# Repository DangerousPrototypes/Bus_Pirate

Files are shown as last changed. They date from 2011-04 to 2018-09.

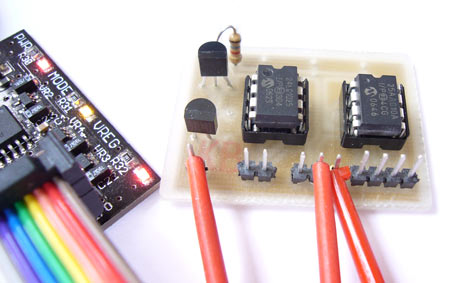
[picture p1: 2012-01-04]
hardware-other/3EEPROM/3EEPROM.v1.jpg

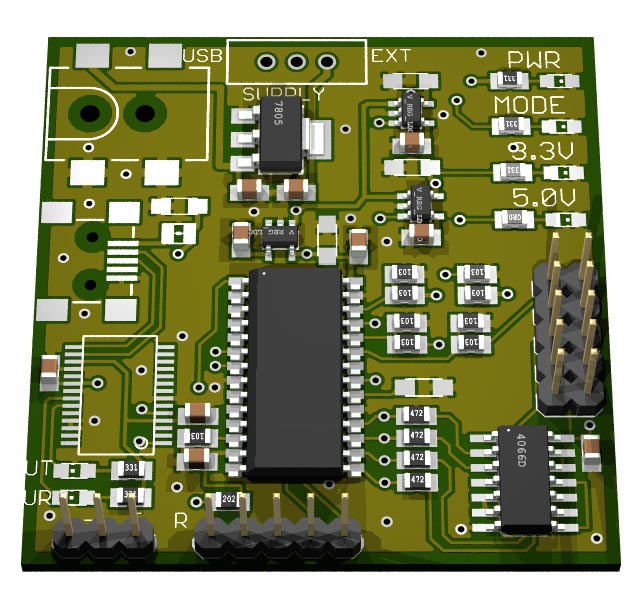
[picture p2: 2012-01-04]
hardware/v2a/BusPirate-v2a-front.jpg

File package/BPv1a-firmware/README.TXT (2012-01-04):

------------------------------------------------------------------
STOP! If you are upgrading from v2 you must install the v4 bootloader first:
http://dangerousprototypes.com/2010/01/18/how-to-bus-pirate-bootloader-v4-upgrade/
v4 BOOTLOADER ONLY!!!
DO NOT TRY TO LOAD THE BOOTLOADER FROM THIS ARCHIVE!!!! 
DO NOT TRY TO LOAD THE V4 FIRMWARE WITH p24QP!!!
------------------------------------------------------------------
Firmware upgrades:

http://dangerousprototypes.com/docs/Bus_Pirate#Firmware_upgrades

1) Enter the bootloader:

Connect PGC and PGD pins of the ICSP header and plug in the USB cable

--+OR+--

Type $ in the Bus Pirate terminal.

With both methods the MODE LED should light.

2) Load the new firmware:

* ds30Loader: just use the GUI (.net/Mono required)
* Pirate-loader (console app for Windows, Linux, Mac) firmware upgrades:

C:\pl>pirate-loader --dev=COM10 --hex=BPv3-Firmware-v1.0.hex

3) re-plug the USB cable to reset the Bus Pirate. The upgrade is complete.

------------------------------------------------------------------
BPv3-Bootloader-v4.4.hex is the same as v4.3 installed with the updater. This file is only for programming the bootlaoder to a new PIC. Use the upgrade package to upgrade:

http://dangerousprototypes.com/docs/Bus_Pirate#Bootloader_upgrades

------------------------------------------------------------------
vX-Firmware-vY(.z_Z).hex

Normal Bus Pirate firmware.
vX - Bus Pirate hardware version.
vY - The Bus Pirate firmware version.
z_Z - The .z_Z versions are translated compiles (currently Spanish and Italian).

vX-STK500v2-vY(-hiz).hex

ATMEL AVR programmer clone for the Bus Pirate hardware. An STK500 v2 protocol compatible firmware for the Bus Pirate, works with AVRDude, AVR Studio v4.11+, etc.
vX - Bus Pirate hardware version (v2go and v3 use the same firmware).
vY - THe STK500v2 clone firmware version.
hiz - The -hiz version of the fimware uses open drain/high impedance outputs. On-board pull-up resistors are enabled (where applicable). The non -hiz version uses normal 3.3volt outputs.

vX-PIC Bootloader-vY.hex

Bootloader to program in a new PIC microcontroller. This is usually only programmed once.
vX - Bus Pirate hardware version.
vY - The Bus Pirate bootloader version.

BPvX-Firmware-vX.X-extras.hex

The BPv3-Firmware-vX.X-extras.hex has a few modes and new stuff we couldn't fit in the main firmware.

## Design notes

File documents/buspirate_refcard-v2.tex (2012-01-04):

\documentclass[10pt]{article}
\usepackage{color}
\begin{document}

%%%%%%%%%%%%%%%%%%%%%%%%%%%%%%%%%%%%%%%%%%%%%%%%%%%%%%%%%%%%%%%%%%%%%%%%%%%%%%%%%%%%%%%%%
%% define colours here 
%% colours are given in normed RGB values
%% whereas (0,0,0) indicates all minimum (black) and (1,1,1) all maximum (white)
%% e.g., \definecolor{MISO}{rgb}{0,0,0}
%% alternatively use 0-255 values by defining the colours with a capital [RGB] parameter
%% e.g., \definecolor{CLK}{RGB}{255,127,0}
%% do not change the given colour names since they correspond to the individual pin
%% These colors are correct at least for my cable dated 10/14/10 ProductNo THM199C4M
%%%%%%%%%%%%%%%%%%%%%%%%%%%%%%%%%%%%%%%%%%%%%%%%%%%%%%%%%%%%%%%%%%%%%%%%%%%%%%%%%%%%%%%%%

\definecolor{GND}{rgb}{0.5,0.1,0.1}  % Brown
\definecolor{V33}{rgb}{1,0,0}        % Red
\definecolor{V5}{rgb}{1,0.5,0}       % Orange
\definecolor{ADC}{rgb}{0.8,0.8,0}    % Yellow (without hurting your eye)
\definecolor{Vpu}{rgb}{0,0.8,0}      % Green
\definecolor{AUX}{rgb}{0,0,1}        % Blue
\definecolor{CLK}{rgb}{0.8,0.4,0.8}  % Purple
\definecolor{MOSI}{rgb}{0.6,0.6,0.6} % Grey
\definecolor{CS}{rgb}{0.9,0.9,0.9}   % White (not really)
\definecolor{MISO}{rgb}{0,0,0}       % Black

%%%%%%%%%%%%%%%%%%%%%%%%%%%%%%%%%%%%%%%%%%%%%%%%%%%%%%%%%%%%%%%%%%%%%%%%%%%%%%%%%%%%%%%%%%%%%%%%%%
% Don't go behind this line without any knowledge of LaTeX and PGF/Tikz... you have been warned
%%%%%%%%%%%%%%%%%%%%%%%%%%%%%%%%%%%%%%%%%%%%%%%%%%%%%%%%%%%%%%%%%%%%%%%%%%%%%%%%%%%%%%%%%%%%%%%%%%

\newcommand{\coltext}[1]{{\textbf{\color{#1}#1}}}

\renewcommand{\arraystretch}{.9}
\setlength{\tabcolsep}{2pt}

\thispagestyle{empty} % just a picture
\sffamily{}\scriptsize
\begin{tabular}{|l|l|l|l|l|l|}
  \hline
    \textbf{SPI}  & \textbf{HiZ} & \textbf{1-Wire} & \textbf{UART} & \textbf{I2C} & \textbf{JTAG}\\ \hline
    \coltext{MISO} & &     & RX &     & TDO \\ \hline
    \coltext{CLK}  & &     &    & SCL & TCK \\ \hline
    \coltext{MOSI} & & OWD & TX & SDA & TDI \\ \hline
    \coltext{CS}   & &     &    &     & TMS \\ \hline
  \hline
    \coltext{AUX} & \multicolumn{5}{|l|}{Auxiliary I/O, freq. probe, PWM} \\ \hline
    \coltext{Vpu} & \multicolumn{5}{|l|}{Input pull-up resistors (0-5V)} \\ \hline
    \coltext{ADC} & \multicolumn{5}{|l|}{A/D\,converter,max.\,6V,10bit,500ksps}\\ \hline
    \textbf{{\color{V5}5V},{\color{V33}3V3}} & \multicolumn{5}{|l|}{Switchable supply, max.\,150mA}\\ \hline
    \coltext{GND} & \multicolumn{5}{|l|}{Ground to test circuit}\\ \hline
  \hline
    \multicolumn{6}{|c|}{\textbf{\tiny BusPirate V3 reference card \hfill dangerousprototypes.com}}\\ 
  \hline
\end{tabular}
\end{document}

%%% Local Variables: 
%%% mode: latex
%%% TeX-master: t
%%% End:

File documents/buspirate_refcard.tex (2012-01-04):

\documentclass[10pt]{article}
\usepackage{pgf}     % drawing in the LaTeX way of life
\usepackage{tikz}    % tikz is not a drawing program
\usepackage[graphics,tightpage,active]{preview} % cut the page to the picture boarders
\setlength{\PreviewBorder}{1pt}  % add a small boarder
\PreviewEnvironment{tikzpicture} 
\begin{document}

%%%%%%%%%%%%%%%%%%%%%%%%%%%%%%%%%%%%%%%%%%%%%%%%%%%%%%%%%%%%%%%%%%%%%%%%%%%%%%%%%%%%%%%%%
%% define colours here 
%% colours are given in normed RGB values
%% whereas (0,0,0) indicates all minimum (black) and (1,1,1) all maximum (white)
%% e.g., \definecolor{MISO}{rgb}{0,0,0}
%% alternatively use 0-255 values by defining the colours with a capital [RGB] parameter
%% e.g., \definecolor{CLK}{RGB}{255,127,0}
%% do not change the given colour names since they correspond to the individual pin
%%%%%%%%%%%%%%%%%%%%%%%%%%%%%%%%%%%%%%%%%%%%%%%%%%%%%%%%%%%%%%%%%%%%%%%%%%%%%%%%%%%%%%%%%

\definecolor{MISO}{rgb}{0,0,0}      % Black
\definecolor{CLK}{rgb}{1,0.5,0}     % Orange
\definecolor{MOSI}{rgb}{1,0,0}      % Red
\definecolor{CS}{rgb}{0.5,0.1,0.1}  % Brown
\definecolor{AUX}{rgb}{0.8,0.8,0}   % Yellow (without hurting your eye)
\definecolor{Vpu}{rgb}{0,0.8,0}     % Green
\definecolor{ADC}{rgb}{0,0,1}       % Blue
\definecolor{V5}{rgb}{0.8,0.4,0.8}  % Violet
\definecolor{V33}{rgb}{0.6,0.6,0.6} % Grey
\definecolor{GND}{rgb}{0.9,0.9,0.9} % White (not really)

%%%%%%%%%%%%%%%%%%%%%%%%%%%%%%%%%%%%%%%%%%%%%%%%%%%%%%%%%%%%%%%%%%%%%%%%%%%%%%%%%%%%%%%%%%%%%%%%%%
% Don't go behind this line without any knowledge of LaTeX and PGF/Tikz... you have been warned
%%%%%%%%%%%%%%%%%%%%%%%%%%%%%%%%%%%%%%%%%%%%%%%%%%%%%%%%%%%%%%%%%%%%%%%%%%%%%%%%%%%%%%%%%%%%%%%%%%

\thispagestyle{empty} % just a picture
  \begin{tikzpicture}[scale=1, node distance=0,inner sep=0.3] % no scaling, no distance between nodes, set inner separation between text and nodes
    \sffamily{}\scriptsize
    \tikzstyle{mynode} = [draw=none,fill=none,anchor=center] % define a own style for all this text-nodes
    
    \matrix[row sep=0.1cm,column sep=0.075cm,anchor=north west] at (0,2.85) % create the first matrix similar to a Latex table 
    {
                                             & \node[mynode] {\textbf{HiZ}}; & \node[mynode] {\textbf{1-Wire}}; & \node[mynode] {\textbf{UART}}; & \node[mynode] {\textbf{I2C}}; & \node[mynode] {\textbf{SPI}}; & \node[mynode] {\textbf{JTAG}};\\
      \node[mynode,right,color=MISO] {\textbf{MISO}};   &                               & \node[mynode]{OWD};              & \node[mynode]{TX};             & \node[mynode]{SDA};           & \node[mynode]{MOSI};          & \node[mynode]{TDI};\\
      \node[mynode,right,color=CLK] {\textbf{CLK}};  &                               &                                                                   & \node[mynode] {SCL};          & \node[mynode]{CLK};         & \node[mynode]{TCK};\\
      \node[mynode,right,color=MOSI] {\textbf{MOSI}};   &                               &                                  & \node[mynode] {RX};            &                               & \node[mynode]{MISO};          & \node[mynode]{TDO};\\
      \node[mynode,right,color=CS] {\textbf{CS}};    &                               &                                  &                                &                               & \node[mynode]{CS};            & \node[mynode]{TMS};\\
    };
    \matrix[row sep=0cm,column sep=0cm,right,anchor=south west] at (0,0.2) % create the second matrix 
    {
    \node[mynode,right,color=AUX]{\textbf{AUX}};      & \node[mynode,right] {Auxiliary I/O, freq. probe, PWM}; \\
    \node[mynode,right,color=Vpu]{\textbf{Vpu}};      & \node[mynode,right] {Input pull-up resistors (0-5V)}; \\
    \node[mynode,right,color=ADC]{\textbf{ADC}};      & \node[mynode,right] {A/D\,converter,max.\,6V,10bit,500ksps}; \\
    \node[mynode,right]{\textbf{{\color{V5}5V},{\color{V33}3.3V}}};  & \node[mynode,right] {Switchable supply, max.\,150mA}; \\
    \node[mynode,right,color=GND]{\textbf{GND}};      & \node[mynode,right] {Ground to test circuit}; \\
    };
    \foreach \y in {0,1,2,3,4}  % draw the grid
        \draw[gray] (0,2.65-0.3*\y)--++(5,0);
    \foreach \x in {0.75,1.275,2.125,2.95,3.55,4.3} 
        \draw[gray] (\x,2.9)--++(0,-1.45);
    \draw[gray] (0,0) rectangle ++(5,2.9); % draw a rectangle with the size of the pcb
    \node[right] at (0,0.1) {\tiny bus-pirate reference card, dangerousprototypes.com, \hspace{0.4cm}V1.0}; % add some infos
  \end{tikzpicture}
\end{document}

%%% Local Variables: 
%%% mode: latex
%%% TeX-master: t
%%% End:

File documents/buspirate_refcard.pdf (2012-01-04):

HiZ | 1-Wire | UART | I2C | SPI | JTAG
MISO | OWD | TX | SDA | MOSI | TDI
CLK | | SCL | CLK | TCK
MOSI | | RX | | MISO | TDO
CS | | | | CS | TMS
AUX | Auxiliary I/O, freq. probe, PWM
Vpu | Input pull-up resistors (0-5V)
ADC | A/D converter,max. 6V,10bit,500ksps
5V,3.3VSwitchable supply, max. 150mA
GND | Ground to test circuit
bus-pirate reference card, dangerousprototypes.com, | V1.0

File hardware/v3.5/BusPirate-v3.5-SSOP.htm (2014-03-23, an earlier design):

Part | Quantity | Value | Package
C1-C6 | 6 | 0.1uF | C603
C7,C8,C9 | 3 | 1uF | C603
C10,C11 | 2 | 10uF | SMC_A
H1,H2,H3,H4 | 4 | MOUNT-PAD-ROUND3.0 | 3,0-PAD
I/O | 1 | HEADER2X5-SHRD-PTH | PINSHRD_PTH_2X05
IC1 | 1 | PIC24FJ64GA002 | SSOP28
IC2 | 1 | FT232RL | SSOP28
IC3 | 1 | 4066 | TSSOP14
ICSP | 1 | HEADER_PRG_PIC_ICSP | HEADER_PRG_1X05_ICSP_B
J1 | 1 | CONN_USB | CONN_USB_MINI-B@1
L1 | 1 | 700mA+ ferrite | WE-KI_0805_B
LED1-LED2,LED2A-LED2,LED3A-LED2,LED4A,LED4A | 8 | | CHIP-LED0805
R1,R5 | 2 | 2K | R603
R2,R3,R4,R6 | 4 | 1K1 | R603
RN1,RN2,RN3 | 3 | 10k | RN8P-4R-CRA06S
U$1 | 1 | | DP-LOGO
U$2 | 1 | | DP-LOGO-BOTTOM
VR1,VR2 | 2 | MCP1801T-3302I/OT | SOT-23-5
VR3 | 1 | MCP1801T-5002I/OT | SOT-23-5

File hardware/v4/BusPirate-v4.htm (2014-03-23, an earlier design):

Part | Quantity | Value | Package
C1-C6,C9,C9 | 8 | 0.1uF | C0603
C7,C8 | 2 | 27pF | C0603
C11,C13 | 2 | 1uF | C0603
C12 | 1 | 1uf | C0603
C14,C15 | 2 | 10uF | SMC_A
D1,D2,D3 | 3 | | SOD123
H1,H2,H3,H4 | 4 | MOUNT-PAD-ROUND2.8 | 2,8-PAD
IC1 | 1 | PIC24FJ256GB106 | TQFP64-10X10
IC2 | 1 | 4066D | SO14
IC3 | 1 | 24AASOT-23-5 | SOT-23-5
ICSP | 1 | ICSP | 1X05
IO | 1 | PINSHRD-PTH-2X06 | PINSHRD_PTH_2X06
JP1 | 1 | | 1X02-S
L1 | 1 | 700mA+ ferrite bead | WE-KI_0805_B
LED1-LED2,LED2A-LED2,LED3A-LED2,LED4A,LED4A | 8 | | CHIP-LED0805
NORMAL,RESET | 2 | SMD_TACT_SMALL | TACT_SWITCH_SMALL
Q1,Q2 | 2 | | SOT23
R1,R2 | 2 | 1K | R0603
R3,R4,R5,R6 | 4 | 1K1 | R0603
R7,R8,R9,R10 | 4 | 2K | R0603
R11,R12,R13,R14 | 4 | 10K | R0603
R15 | 1 | 100K | R0603
RN1,RN2,RN3 | 3 | 10k | RN8P-4R-CRA06S
U$1 | 1 | | DP-LOGO
USB | 1 | USB mini-b | CONN_USB_MINI-B
VR1,VR2 | 2 | MCP1801T-3302I/OT | SOT-23-5
VR3 | 1 | MCP1801T-5002I/OT | SOT-23-5
X1 | 1 | CRYSTAL_212M_ | 4X6

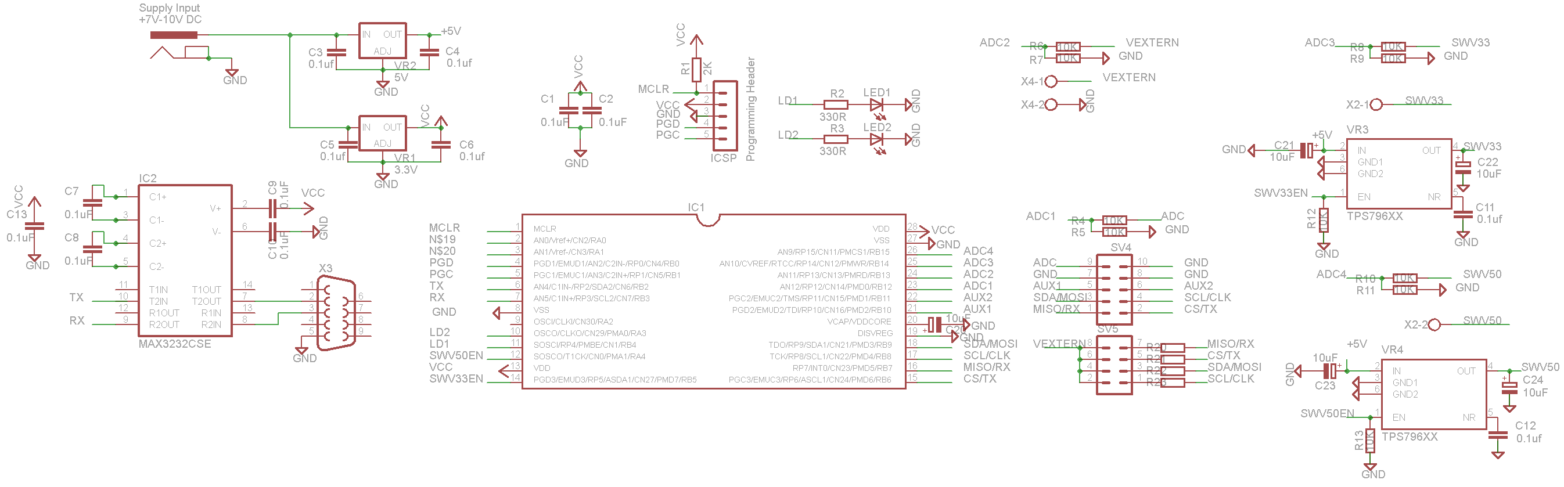
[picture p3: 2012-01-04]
hardware/v1a/cct.png

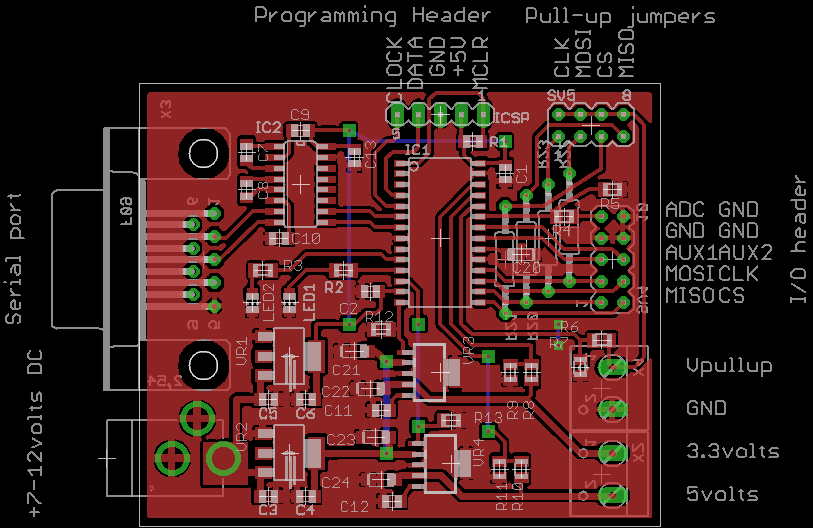
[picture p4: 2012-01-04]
hardware/v1a/brd.png

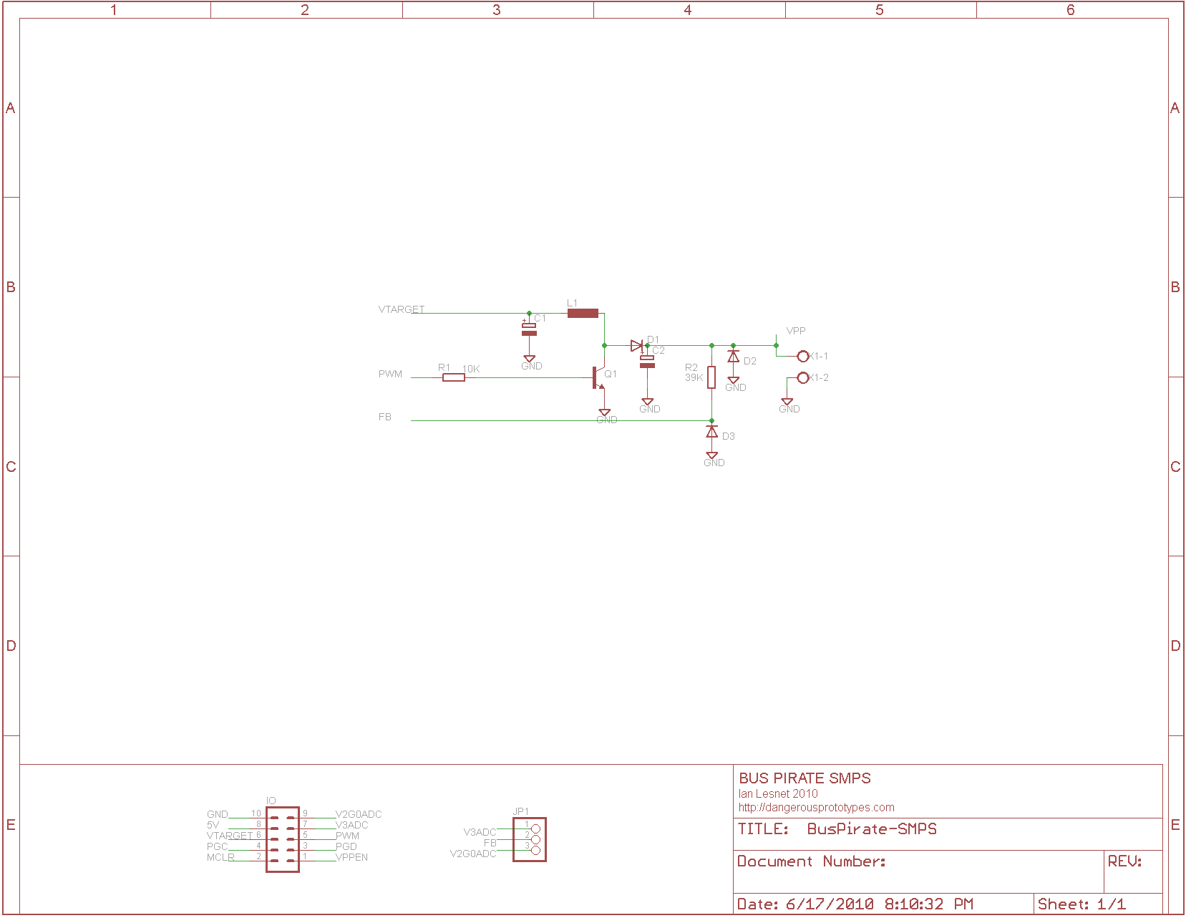
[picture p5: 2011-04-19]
hardware-other/SMPS/BusPirate-SMPS.sch.png

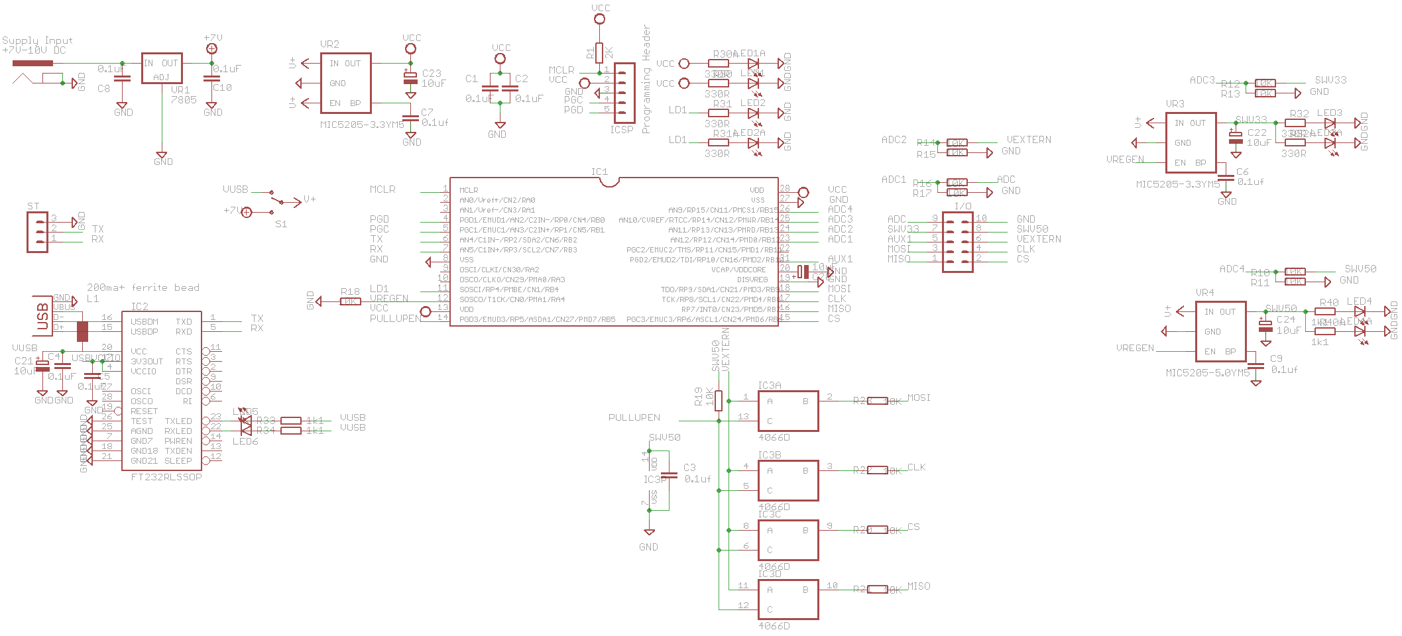
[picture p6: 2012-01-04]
hardware/v2a/cct.png

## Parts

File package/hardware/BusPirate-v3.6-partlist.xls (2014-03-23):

Electronic Engineering BOM List v1.0
Product Name： Bus Pirate
Version： Version v3.6
Issue Date： 05/01/12
Item No. (序号) | Catalog (分类） | Reference Des (上件位置) | Part_Description (规格描述) | Part_Value （元件值） | Part_Package （元件封装） | Qty (用量) | Manufacturers Name (使用厂牌名称) | Manufacturers Part No. (使用厂牌型号) | Distributors Name （供应商名称） | Distributors Part No. (供貨商型号) | Unit Price （单价） | Price Break To Use （价格分段的购买量） | Stock Status （库存状态） | Notes/Remark （备注）
1 | Capacitor | C1,C2,C3,C4,C5,C6 | Ceramic Capacitor | 0.1uF | C603 | 6
2 | Capacitor | C7, C8,C9 | Ceramic Capacitor | 1uF | C603 | 3
3 | Capacitor | C10,C11 | Tantalum capacitor | 10uF | SMC_A | 2
4 | OTHER | I/O | 05x2 shrouded header. Note: Shrouded | M05X2SHD | 2X5-SHROUDED | 1
5 | IC | IC1 | PIC microcontroller | PIC24FJ64GA002SS | SSOP28DB | 1
6 | IC | IC2 | FT232RLSSOP |  | SSOP28DB | 1
7 | IC | IC3 | 74HC4066 or CD4066 |  | TSSOP14 | 1
8 | OTHER | ICSP | 0.1” male pin header | M05X1PTH | 1X05 | 1
9 | OTHER | J1 | CONN_USB |  | CONN_USB_MINI-B | 1
10 | OTHER | L1 | 700mA+ ferrite bead | 700mA+ | L805 | 1
11 | OTHER | LED1 – 4 | Yellow LEDs |  | LED0805 | 4
12 | Resister | R1,R5 |  | 2K | R603 | 2
13 | Resister | R2,R3,R4,R6 |  | 1K1 | R603 | 4
14 | OTHER | RN1,RN2,RN3 | 4 resistor array | 10k | R0603 x 4 array | 3
15 | OTHER | VR1,VR2 | 3.3volt LDO voltage regulator 150mA with enable (example MCP1801T-3302I/OT) | MCP1801T-3302I/OT | SOT23-5 | 2 | http://ph.mouser.com/ProductDetail/Microchip-Technology/MCP1801T-3302I-OT/
16 | OTHER | VR3 | 5volt LDO voltage regulator 150mA with enable (example MCP1801T-5002I/OT) | MCP1801T-5002I/OT | SOT23-5 | 1 | http://ph.mouser.com/ProductDetail/Microchip-Technology/MCP1801T-5002I-OT/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
1. Recommended Distributors: Digi-Key, Mouser, Avnet Express, Farnell.
2. Catalog: Capacitor,Resister,Diode,Connector,Transistor,IC,PROTECTOR CATEGORY,OTHER
3. Required Fields: Item No, Reference Des, Qty, Catalog, Part_Value, Part_Package, Part_Description
Optional Fields: Manufacturers Name, Manufacturers Part No, Distributors Name, Distributors Part No, Unit Cost, Price break to use, Stock Status，Notes/Remark
 |  |  |  |  |  |  |  |  | by Heidi Luo
 |  |  |  |  |  |  |  |  | 01.May/2011

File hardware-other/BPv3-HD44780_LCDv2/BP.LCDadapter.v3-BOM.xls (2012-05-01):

Electronic Engineering BOM List v1.0
Product Name： Bus Pirate LCD adapter
Version： Version 3
Issue Date： 5/01/12
Item No. (序号) | Catalog (分类） | Reference Des (上件位置) | Part_Description (规格描述) | Part_Value （元件值） | Part_Package （元件封装） | Qty (用量) | Manufacturers Name (使用厂牌名称) | Manufacturers Part No. (使用厂牌型号) | Distributors Name （供应商名称） | Distributors Part No. (供貨商型号) | Unit Price （单价） | Price Break To Use （价格分段的购买量） | Stock Status （库存状态） | Notes/Remark （备注）
1 | OTHER | ANODE,CATH,CPWM | 0.1” pin header |  | 1X02 | 1
2 | OTHER | ANODE,CATH,CPWM | 0.1” pin header |  | 1X03 | 1
3 | Capacitor | C1 |  | 0.1uF | C0805 | 1
4 | IC | IC1 | 74HCT595D (NOTE: Please make it "HCT") |  | SO16 | 1
5 | OTHER | JP1 | M05X2SHD |  | 2X5-SHROUDED | 1
6 | OTHER | LCD | 0.1” Female header |  | 1X16 | 1
7 | OTHER | LED1 | Yellow LED |  | CHIP-LED0805 | 1
8 | Resister | R1 |  | 10K trim resistor 6mm | CA6V | 1
9 | Resister | R2,R4 |  | 1K | M0805 | 2
10 | Resister | R5 |  | 100R trim resistor 6mm | CA6V | 1
11 | Transistor | T1 | NPN 800ma+ (BC818) |  | SOT23-BEC | 1
12 | OTHER | Jumpers | 0.1” jumper on ANODE,CATH |  |  | 2
13 | OTHER | Cable | 2x5 to 2x5 ribbon cable |  |  | 1
1. Recommended Distributors: Digi-Key, Mouser, Avnet Express, Farnell.
2. Catalog: Capacitor,Resister,Diode,Connector,Transistor,IC,PROTECTOR CATEGORY,OTHER
3. Required Fields: Item No, Reference Des, Qty, Catalog, Part_Value, Part_Package, Part_Description
Optional Fields: Manufacturers Name, Manufacturers Part No, Distributors Name, Distributors Part No, Unit Cost, Price break to use, Stock Status，Notes/Remark
 |  |  |  |  |  |  |  |  | by Heidi Luo
 |  |  |  |  |  |  |  |  | 01.5/2012

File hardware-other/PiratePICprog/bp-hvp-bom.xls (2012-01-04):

Part | Quantity | Value
C1 | 1 | 470pF capacitor (0805) (http://www.mouser.com/ProductDetail/Xicon/140-CC501N471J-RC/)
C2, C3, C6 | 3 | 0.1uF/50V capacitor (0805) (http://www.mouser.com/Search/ProductDetail.aspx)
C4 | 1 | 10uF/10V capacitor (SMC_A) (http://www.mouser.com/Search/ProductDetail.aspx)
C5 | 1 | 4.7uF/35V (SMD_A5) (http://www.mouser.com/Search/ProductDetail.aspx)
D1, D2 | 2 | 1N5819, 20V, 1A+ diode (SOD123) (http://www.mouser.com/Search/ProductDetail.aspx)
IC1 | 1 | MC34063AD (SO08) (http://www.mouser.com/Search/ProductDetail.aspx)
JP1 | 1 | female 02x5 plug (http://www.mouser.com/Search/ProductDetail.aspx)
L1 | 1 | 680uH/0.12A inductor (L4532P) (http://www.mouser.com/Search/ProductDetail.aspx?R=84684Cvirtualkey58010000virtualkey580-84684C)
PIC-ICSP | 1 | 1X05 0.1” pin header (http://www.mouser.com/Search/ProductDetail.aspx)
POWER | 1 | 1X03 0.1” pin header (http://www.mouser.com/Search/ProductDetail.aspx)
R1 | 1 | 20K resistor (0805) (http://www.mouser.com/Search/ProductDetail.aspx)
R2 | 1 | 2K2 resistor (0805) (http://www.mouser.com/Search/ProductDetail.aspx)
R3 | 1 | 4R7 resistor (0805) (http://www.mouser.com/ProductDetail/Xicon/260-47-RC/)
R4 | 1 | 180R resistor (0805) (http://www.mouser.com/Search/ProductDetail.aspx)
R5 | 1 | 39K resistor (0805) (http://www.mouser.com/Search/ProductDetail.aspx?R=260-39K-RCvirtualkey21980000virtualkey260-39K-RC)
R6 | 1 | 100K resistor (0805) (http://www.mouser.com/Search/ProductDetail.aspx)
R7 | 1 | 100R resistor (0805) (http://www.mouser.com/Search/ProductDetail.aspx)
R8-R12 | 5 | 10K resistor (0805) (http://www.mouser.com/Search/ProductDetail.aspx)
T1, T2 | 2 | NPN, 200mA+, 30+hfe transistor (SOT23-BEC) (http://www.mouser.com/Search/ProductDetail.aspx)
T3,T4 | 2 | PNP, 600mA+, 40+ hef transistor (SOT23-BEC) (http://www.mouser.com/Search/ProductDetail.aspx)
Jumper | 1 | 1 jumper on the power header

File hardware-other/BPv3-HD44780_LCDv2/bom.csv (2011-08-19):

Part | Value | Package
BLA | 1x2 0.1” pin header | 1X02
BLC | 1x2 0.1” pin header | 1X02
C1 | 0.1uF capacitor | 805
IC1 | 74HCT595 | SO16
JP1 | 5X2 0.1” shrouded header | 2X5-SHROUDED
LCD1 | 14x1 0.1” female header | 14x1 (female)
LED1 | Yellow LED | 805
R1 | 10K potentiometer | CA6V/6mm
R2 | 1K resistor | 805
CABLE | 6cm 1x10 cable with 2 2x5 female connectors
 | This cable connects the Bus Pirate to the LCD adapter
 | It needs 2x5 female connectors on each end.
 | Length can be very short >6cm.

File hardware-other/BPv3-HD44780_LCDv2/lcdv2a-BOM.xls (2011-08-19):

Partlist
Bus Pirate LCD Adapter v2a
Where Labs, LLC
Contact: Ian Lesnet (ian@wherelabs.com)
Part | Value | Package
ANODE | 1x2 0.1” pin header | 1X02
CATH | 1x2 0.1” pin header | 1X02
C1 | 0.1uF capacitor | 805
IC1 | 74HCT595 | SO16 | **note orientation
JP1 | 5X2 0.1” shrouded header | 2X5-SHROUDED | **note orientation
LCD1 | 16x1 0.1” female header | 16x1 (female)
LED1 | Yellow LED | 805 | **note orientation
R1 | 10K potentiometer | CA6V/6mm
R2 | 1K resistor | 805
CABLE | 6cm 1x10 cable with 2 2x5 female connectors
 | This cable connects the Bus Pirate to the LCD adapter
 | It needs 2x5 female connectors on each end.
 | Length can be very short >6cm.

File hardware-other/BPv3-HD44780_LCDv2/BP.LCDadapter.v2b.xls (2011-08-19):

Bus Pirate LCD adapter v2b
Ian Lesnet (ian@wherelabs.com)
Part | Quantity | Value | Package
ANODE,CATH,CPWM | 3 | 0.1” pin header | 1X02
C1 | 1 | 0.1uF | C0805
IC1 | 1 | 74HCT595D | SO16
JP1 | 1 | M05X2SHD | 2X5-SHROUDED
LCD | 1 | 0.1” Female header | 1X16
LED1 | 1 | Yellow LED | CHIP-LED0805
R1 | 1 | 10K trim resistor 6mm | CA6V
R2,R4 | 2 | 1K | M0805
R5 | 1 | 100R trim resistor 6mm | CA6V
T1 | 1 | NPN 800ma+ (BC818) | SOT23-BEC
Jumpers | 2 | 0.1” jumper on ANODE,CATH
Cable | 1 | 2x5 to 2x5 ribbon cable

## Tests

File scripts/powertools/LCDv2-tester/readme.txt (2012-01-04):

Latest instructions and version:
http://dangerousprototypes.com/docs/Bus_Pirate_LCD_adapter_v2#Production_testing_procedure

Setup a Bus Pirate for testing
#Use Bus Pirate with firmware v5.x
#Connect the Bus Pirate to USB
#Run lcdtest.exe -d COMx where COMx is the Bus Pirate serial port.

Test procedure
#Connect the LCD adapter the the Bus Pirate
#Press space to run the test
#Verify LED1 on the adapter is blinking (other outputs will also blink)
#Press space to reset the test
#Remove the LCD adapter
#Repeat with #1

Possible no LED solutions
*Check LED1, R2 (solder, failed)
*Check IC1 (solder, failed)
*Check IO connector (solder)

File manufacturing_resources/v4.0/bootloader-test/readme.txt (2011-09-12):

http://dangerousprototypes.com/docs/Bus_Pirate_v4_firmware_updates

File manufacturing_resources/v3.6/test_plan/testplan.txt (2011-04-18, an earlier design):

http://dangerousprototypes.com/docs/Self-test_guide

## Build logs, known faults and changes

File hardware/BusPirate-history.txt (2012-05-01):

May 1, 2012
v4d
*Updated PCB to fit DP6037 standard PCB footprint
*Updated silk with big logos

v3.6
*Renamed v3.5e to avoid confusion with cases

v3.5e
*Updated to fit DP6037 standard PCB footprint
*Updated silk with big logos

****Old history****

v4.1 (lost variant)
*Small rerouting of v4
*not yet resized to fit v4a case
*Lost or abandonded

v4a
*v4 resized to fit Seeed case. First production version.

v4
*Original pre-production version 4 sold at Seeed for $50.

v3.5c
*Replaced 4066 control trace

v3.5b
*Header keyed to match seeed cable

v3.5
*Two versions, SOIC and SSOP PIC chips
*Same as v3b with reduced part count
*Resistors moved to resistor arrays
*Centered connectors and jacks
*SSOP size 4066 (instead of SOIC on v3)

v3b
*Same as v3a 
*Ceremic instead of tantalum capacitors for the 3.3 and 5volt regulators

v3a
*First Dangerous Prototypes version
*Reshaped the original v2go hardware
*Moved to SOIC PIC chip

v2go
*Original Seeed Studio preorder Bus Pirate hardware

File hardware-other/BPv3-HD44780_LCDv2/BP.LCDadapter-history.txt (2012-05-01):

v3
*Silk update with logo
*Board shape change to fit standard PCB footprint for cases
*PART REDUCTION: v2c uses 3pcs 1x2 pin headers. v3 uses 1pc 1x2 and 1pcs 1x3

v2c
*Silk cleanup

v2b
*Added backlight adjustable resistor
*Silk cleanup

v2a
*Added T1 and R4 to do backlight dimming with the Bus Pirate PWM.

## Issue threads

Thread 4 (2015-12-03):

0Tis Elevat0r C0mpany R3mote Stati0n Pr0tocol

nicolas-schurando, 2015-12-03:
I am importing this issue from the old google code repository, https://code.google.com/p/the-bus-pirate/issues/detail?id=37.

alvaro.e...@gmail.com, Sep 5, 2009
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

ianles...@gmail.com, Sep 6, 2009
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

BrentBXR, Nov 22, 2011
>0 1c th4t 15 s0o c0ol. I would imagine people working on elevators have specialized equipment todo so. I would never take my bus pirate to go hacking elevators. Not that the bus pirate shouldn't have every protocol it can fit. It just seems this would be on the rarely, if ever, used list. I doubt Ian or the DP guys could make time to implement it when other, more used, protocols are still pending.
>
>co0l u5ag3 of num8er5 a5 13773r5 7h0, rather annoying really. :P

Although this was discussed many years ago now, it does not appear the questions have been answered, and I believe it could still be of interest for some people. At least, for me it is. So here is some information I have gathered so far.

On modern generations (gen2 for example), the bus is composed of 4 wires. L1 (for data), L2 (for clock), +30VDC and GND. It would make sense for the clock to be generated by the main controller. I would assume it is some kind of I2C.

As the bus runs for dozens of meters down the hoistway, special care should probably be taken when designing an adaptation circuit for the bus pirate since capacitance and pull-up resistor values will have an impact on achievable data rates.

Cheers.

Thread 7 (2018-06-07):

Where could I read more about Bus Pirate v5.0 ?

mikebdp2, 2018-06-07:
@vimark I can't find any mention of " Bus Pirate v5.0 " at DangerousPrototypes website ( no new results at http://dangerousprototypes.com/blog/category/bus-pirate/ ). Where could I read more about Bus Pirate v5.0 ? And is it a completely new hardware, or its actually based on Bus Pirate v3 and should be called Bus Pirate v3.9 or v3.10 not to confuse the people?

vimark, 2018-06-07:
Sorry, We don't have that version yet.

mikebdp2, 2018-06-07:
@vimark Thank you for reply! Please tell, is BPv5 a completely new hardware, or its actually based on Bus Pirate v3 and is fully compatible with it by its' bootloader/firmware ? Just need to clarify...

vimark, 2018-06-08:
@mikebdp2 From hardware point of view its completely new. Sorry, but I can't comment  much on the firmware side as I only do on hardware on it.

kallisti5, 2018-07-02:
The community firmware project has gotten pretty advanced and has a *LOT* of fixes and cleanups of the original BusPirate firmware.  Dangerous Prototypes would be pretty silly not to leverage their advances in any "theoretical" new BusPirate hardware.

mikebdp2, 2018-08-16:
@vimark I fully support @kallisti5 point of view. Please improve your collaboration with the community

mikebdp2, 2018-08-16:
@ian Hope you could check this thread above, and this one also - https://github.com/BusPirate/Bus_Pirate/issues/98

kallisti5, 2018-08-16:
I should also mention that the community firmware would *love* to work with DP if needed.. but someone from DP needs to collaborate.

kallisti5, 2018-08-16:
also, looking at this it doesn't seem DP is interested at the moment in the community firmware and all of it's fixes and improvements:

https://github.com/DangerousPrototypes/Bus_Pirate/tree/firmware_v8_official

DangerousPrototypes, 2018-08-16:
Hey Mike,

We're really working on it. I'm stuck behind the Chinese firewall and its difficult to explain the extent to which the internet doesn't work. This is the first email I've received on this chain, I don't know of there are others. Half the time github access is blocked here.

I'm actually moving back to Amsterdam starting in September and we have a bunch of stuff ready to roll out. For example we managed to get buspirate.com back from the spammers that took over after hack a day and have setup a site there with continuous development integration for all versions of the bus pirate (instantly compiling the latest git commits and packaging them into releases). We plan to make this open source too to help other projects focus more on coding and less on tedious release management.

I've already reworked v3/4/5 code base with about two dozen fixes. I just need to be where the internet works to start posting about it.

V5 is a minor tweak, but v NG1 is a complete remake, and NG2 is probably the ultimate tool we can make for cheap with modern chips.

⁣Cheers,

Ian

Sent from a mobile device, please excuse my brevity.

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

DangerousPrototypes, 2018-08-16:
Sjaak and I have reviewed and have a private branch to merge in eventually. We like many of the changes, but there's a lot of stuff that we want to do differently based on our experience with the compilers and code base.

⁣Cheers,

Ian

Sent from a mobile device, please excuse my brevity.

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

kallisti5, 2018-08-16:
No worries, that's all fine.   We have been stuck with silence from DP for a few years now, so we really don't know what to expect.

The https://github.com/BusPirate/Bus_Pirate source repository is **really** in good shape thanks to @agatti  The code has been cleaned up, updated to the most recent MPLab X, and had a **huge** number of bug fixes (and new features) introduced.

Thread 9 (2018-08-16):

DP Forums - Cant register: reCAPTCHA V1 IS SHUTDOWN

mikebdp2, 2018-08-16:
Dear Administrators, @vimark and @ian, I am writing to you with a really urgent matter. New members can't register at DangerousPrototypes forums, because

Confirmation of Registration:
reCAPTCHA V1 IS SHUTDOWN
Direct site owners to http://g.co/recaptcha/upgrade

You could try registering a new account by yourself, to easily see this problem. Please do something, maybe upgrade this captcha switch to the alternative domestic captcha to avoid depending on the stupid google

http://dangerousprototypes.com/forum/ucp.php?mode=register

Please read this thread - https://github.com/BusPirate/Bus_Pirate/issues/98 - btw it also describes the questions of DP collaboration with the community

DangerousPrototypes, 2018-08-16:
Hey ya,

Im super sorry about the issue and I'm aware of it. Its on our list. Edward is working on it. Its really hard because phpbb is less than an ideal code base to work with. We need a path forward that will maintain current integration with the site. We also need akismet or similar spam filtering because phpbb is a spam magnet. If we upgrade phpbb then we loose our current home grown spam hammer filter. I also refuse to use the Google "choose the store fronts" "choose the street signs" because it is blocked in China and elsewhere, and also its so frustrating to use.

⁣Cheers,

Ian

Sent from a mobile device, please excuse my brevity.

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

DangerousPrototypes, 2018-08-16:
Part of that is everyone uses CDC hosted libraries (jquery, font awesome, bootstrap, Google fonts, etc) like life depends on them. Half these are blocked in China and time out and break web pages even if the page itself isn't blocked. It causes a huge amount of lag outside China too.

If you look at how we did dirtypcbs.com we use raw javascript when possible, and if we include a library we host it locally (out of nessesity). Buspirate.com is made the same way.

I'm in Shenzhen at the moment running test batches of new hardware. I'll be back in Amsterdam on the 4th to start dealing with updates and community side.

Thanks for liking what we do! It means a lot. We are hard at work readying the new stuff for fall. Getting all these emails today gives us lots of encouragement that someone will be interested in our progress.

⁣Cheers,

Ian

Sent from a mobile device, please excuse my brevity.

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

mikebdp2, 2018-09-19:
@DangerousPrototypes Thank you very much to you and your team for fixing the captcha. This issue could be closed now...

theolas, 2023-11-27:
@DangerousPrototypes Hi, sorry to bother, it seems like the site is not secured (expired certificate?) and the email validation emails are not reaching the mailboxes, so new accounts cannot be created.

DangerousPrototypes, 2024-01-29:
Please try our new site forum.buspirate.com. I'm going to rip all the old DP sites to flatfile because the underlying tech is too old to migrate anywhere. Sorry for a very late reply, I think we touched bases on twitter too.

Closed 2018-09-19.

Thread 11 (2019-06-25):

Firmware Updating

kkey00, 2019-06-25:
So I updated the firmware on my bus pirate v3 and it gave me the success message. However when I try to use screen to check the firmware version the interface doesn't function. I can put the board in boot loader mode with a jumper, but not through the console anymore. The power LED is on and so is the VREG LED. Any help is appreciated!

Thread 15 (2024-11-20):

si7021 command not working

grymoire, 2024-11-20:
I can follow the [Device Demo for SL7021](https://firmware.buspirate.com/devices/si7021), and all of the individual commands work, but the command "si7021" returns an error
```
I2C> si7021           
Read temperature and humidity from SI7021/HTU21/SHT21 sensor
Error reading humidity data
```
[BUGSI7021.txt](https://github.com/user-attachments/files/17835094/BUGSI7021.txt)

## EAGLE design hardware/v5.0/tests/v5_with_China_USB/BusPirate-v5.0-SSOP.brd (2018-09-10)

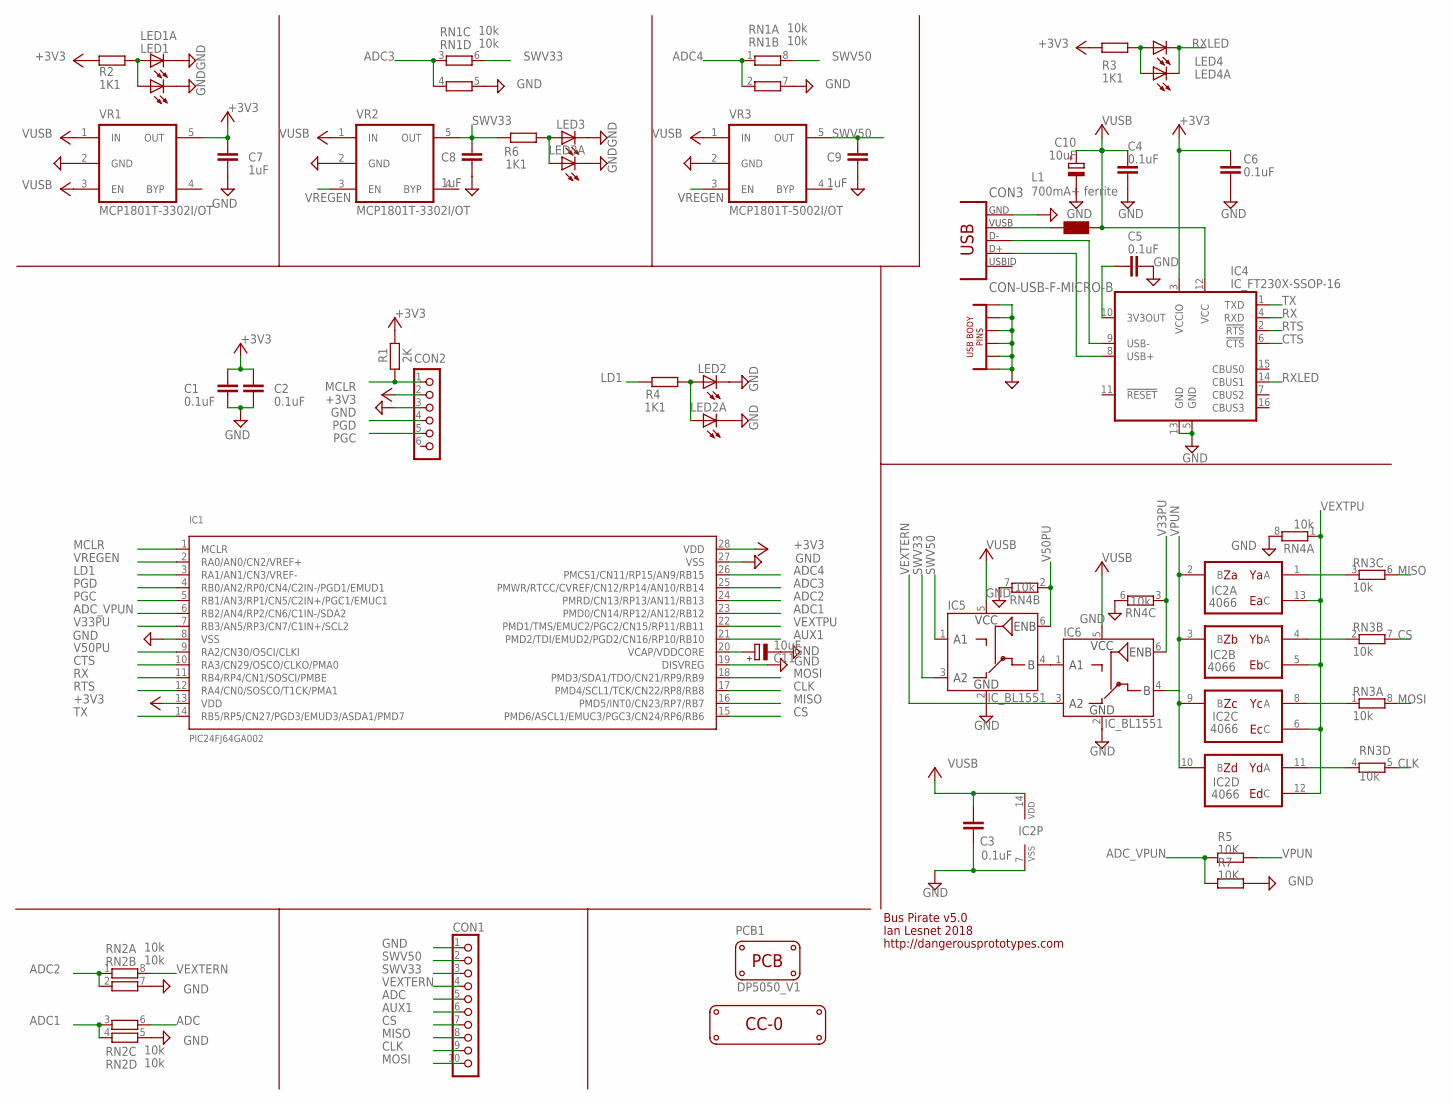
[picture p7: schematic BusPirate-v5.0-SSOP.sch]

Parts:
C1, C2, C3, C4, C5, C6: 0.1uF; C603
C7, C8, C9: 1uF; C603
C10, C11: 10uF; SMC_A
CON1: CON_HEADER_1X10-RIGHT_ANGLED_PTH_SHROUDED; M1X10_MALE_RIGHT_ANGLES_PTH_SHROUDED
CON2: CON_HEADER_1X06-PTH; M1X6
CON3: CON-USB-F-MICRO-B; CON_USB_MICRO-B-1-MD05SMXXX-01
IC1: PIC24FJ64GA002; SSOP28
IC2: 4066; TSSOP14
IC4: IC_FT230X-SSOP-16; SSOP-16-FTDI
IC5, IC6: IC_BL1551; SOT-363
L1: 700mA+ ferrite; WE-KI_0805_B
LED1, LED1A, LED2, LED2A, LED3, LED3A, LED4, LED4A: LED-0805; LED-805
LOGO1: LOGO_CC-0
PCB1: PCB_DP_SQUARE-5X5; DP5050_V1
R1: 2K; R603
R2, R3, R4, R6: 1K1; R603
R5, R7: 10K; R603
RN1, RN2, RN3, RN4: 10k; RN8P-4R-CRA06S
VR1, VR2: MCP1801T-3302I/OT; SOT-23-5
VR3: MCP1801T-5002I/OT; SOT-23-5

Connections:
$N26: CON3.P1 (VUSB), L1.2 (1)
+3V3: C1.1, C2.1, C6.1, C7.1, CON2.2, IC1.13 (VDD), IC1.28 (VDD), IC4.3 (VCCIO), R1.2, R2.2, R3.2, VR1.5 (OUT)
ADC: CON1.5, RN2.6 (2)
ADC1: IC1.23 (PMD0/CN14/RP12/AN12/RB12), RN2.3 (1), RN2.4 (1)
ADC2: IC1.24 (PMRD/CN13/RP13/AN11/RB13), RN2.1, RN2.2 (1)
ADC3: IC1.25 (PMWR/RTCC/CVREF/CN12/RP14/AN10/RB14), RN1.3 (1), RN1.4 (1)
ADC4: IC1.26 (PMCS1/CN11/RP15/AN9/RB15), RN1.1, RN1.2 (1)
ADC_VPUN: IC1.6 (RB2/AN4/RP2/CN6/C1IN-/SDA2), R5.2, R7.2
AUX1: CON1.6, IC1.21 (PMD2/TDI/EMUD2/PGD2/CN16/RP10/RB10)
CLK: CON1.9, IC1.17 (PMD4/SCL1/TCK/CN22/RP8/RB8), RN3.5 (2)
CS: CON1.7, IC1.15 (PMD6/ASCL1/EMUC3/PGC3/CN24/RP6/RB6), RN3.7 (2)
CTS: IC1.10 (RA3/CN29/OSCO/CLKO/PMA0), IC4.6 (!CTS)
GND: C1.2, C2.2, C3.2, C4.2, C5.2, C6.2, C7.2, C8.2, C9.2, C10.-, C11.-, CON1.1, CON2.3, CON3.GND1, CON3.GND2, CON3.GND3, CON3.GND4, CON3.GND5, CON3.GND6, CON3.P5 (GND), IC1.8 (VSS), IC1.19 (DISVREG), IC1.27 (VSS), IC2.7 (VSS), IC4.5 (GND), IC4.13 (GND), IC5.2 (GND), IC6.2 (GND), LED1.C, LED1A.C, LED2.C, LED2A.C, LED3.C, LED3A.C, R7.1, RN1.5 (2), RN1.7 (2), RN2.5 (2), RN2.7 (2), RN4.6 (2), RN4.7 (2), RN4.8 (2), VR1.2 (GND), VR2.2 (GND), VR3.2 (GND)
LD1: IC1.3 (RA1/AN1/CN3/VREF-), R4.2
MCLR: CON2.1, IC1.1 (MCLR), R1.1
MISO: CON1.8, IC1.16 (PMD5/INT0/CN23/RP7/RB7), RN3.6 (2)
MOSI: CON1.10, IC1.18 (PMD3/SDA1/TDO/CN21/RP9/RB9), RN3.8 (2)
unnamed: IC2.11 (A), RN3.4 (1)
unnamed: IC2.8 (A), RN3.1
unnamed: C11.+, IC1.20 (VCAP/VDDCORE)
unnamed: IC2.4 (A), RN3.2 (1)
unnamed: IC2.1 (A), RN3.3 (1)
unnamed: LED2.A, LED2A.A, R4.1
unnamed: LED1.A, LED1A.A, R2.1
unnamed: C5.1, IC4.10 (3V3OUT)
unnamed: IC5.4 (B), IC6.1 (A1)
unnamed: LED4.A, LED4A.A, R3.1
unnamed: CON3.P3 (D+), IC4.8 (USB+)
unnamed: CON3.P2 (D-), IC4.9 (USB-)
unnamed: LED3.A, LED3A.A, R6.1
PGC: CON2.5, IC1.5 (RB1/AN3/RP1/CN5/C2IN+/PGC1/EMUC1)
PGD: CON2.4, IC1.4 (RB0/AN2/RP0/CN4/C2IN-/PGD1/EMUD1)
RTS: IC1.12 (RA4/CN0/SOSCO/T1CK/PMA1), IC4.2 (!RTS)
RX: IC1.11 (RB4/RP4/CN1/SOSCI/PMBE), IC4.4 (RXD)
RXLED: IC4.14 (CBUS1), LED4.C, LED4A.C
SWV33: C8.1, CON1.3, IC5.3 (A2), R6.2, RN1.6 (2), VR2.5 (OUT)
SWV50: C9.1, CON1.2, IC5.1 (A1), RN1.8 (2), VR3.5 (OUT)
TX: IC1.14 (RB5/RP5/CN27/PGD3/EMUD3/ASDA1/PMD7), IC4.1 (TXD)
V33PU: IC1.7 (RB3/AN5/RP3/CN7/C1IN+/SCL2), IC6.6 (ENB), RN4.3 (1)
V50PU: IC1.9 (RA2/CN30/OSCI/CLKI), IC5.6 (ENB), RN4.2 (1)
VEXTERN: CON1.4, IC6.3 (A2), RN2.8 (2)
VEXTPU: IC1.22 (PMD1/TMS/EMUC2/PGC2/CN15/RP11/RB11), IC2.5 (C), IC2.6 (C), IC2.12 (C), IC2.13 (C), RN4.1
VPUN: IC2.2 (B), IC2.3 (B), IC2.9 (B), IC2.10 (B), IC6.4 (B), R5.1
VREGEN: IC1.2 (RA0/AN0/CN2/VREF+), VR2.3 (EN), VR3.3 (EN)
VUSB: C3.1, C4.1, C10.+, IC2.14 (VDD), IC4.12 (VCC), IC5.5 (VCC), IC6.5 (VCC), L1.1 (2), VR1.1 (IN), VR1.3 (EN), VR2.1 (IN), VR3.1 (IN)

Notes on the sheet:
Bus Pirate v5.0
Ian Lesnet 2018
http://dangerousprototypes.com

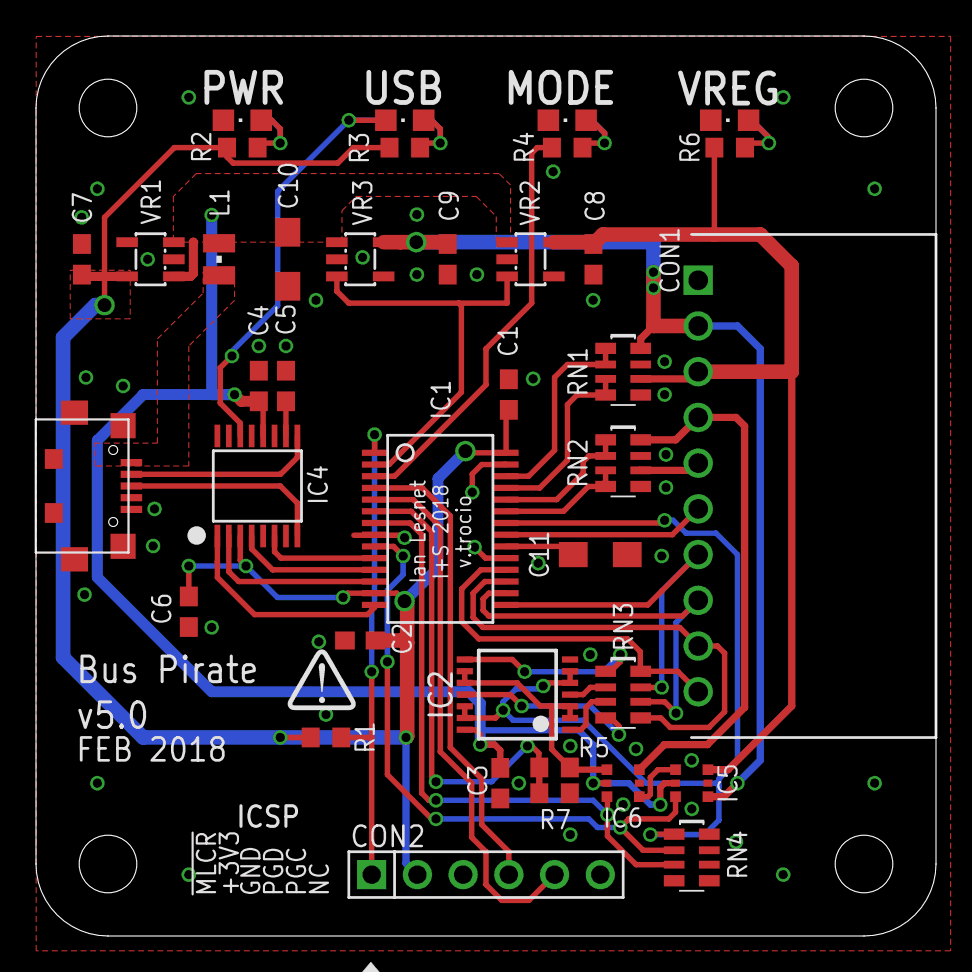
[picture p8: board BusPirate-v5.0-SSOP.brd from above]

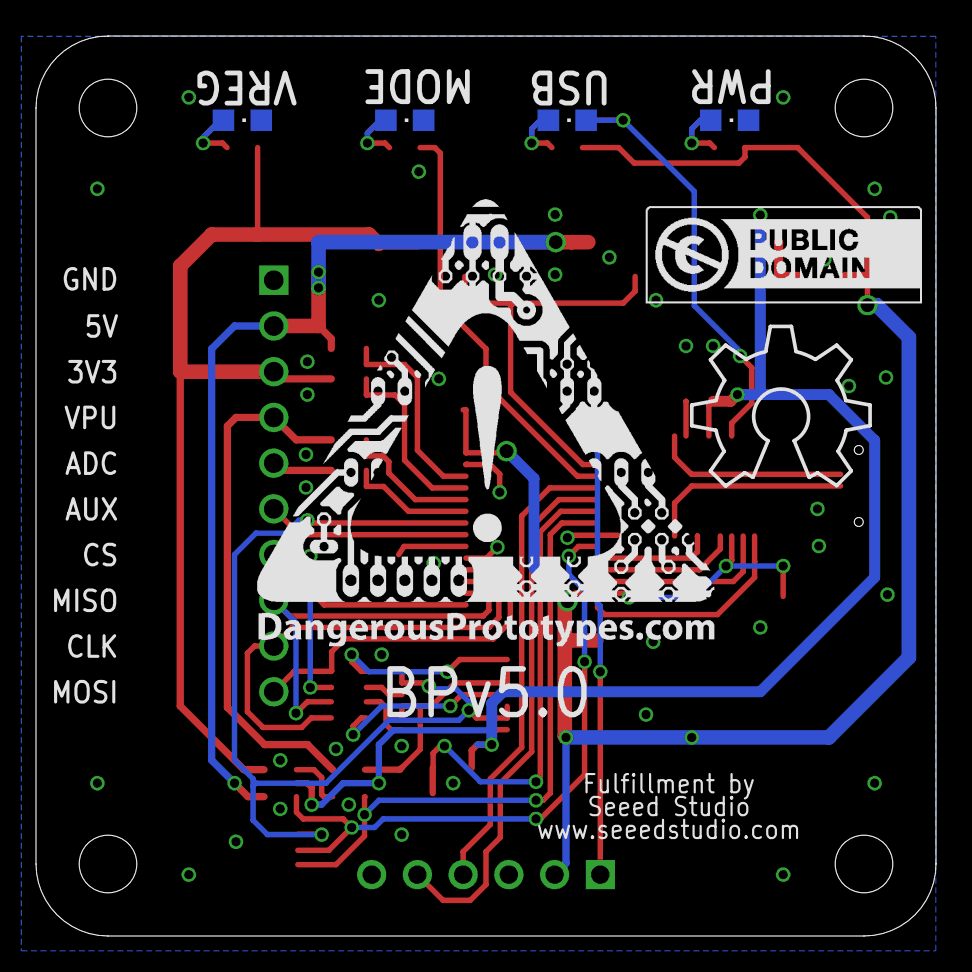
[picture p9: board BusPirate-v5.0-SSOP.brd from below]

Board: 2 copper layers, 50.0 x 50.0 mm, 47 parts (7 on the bottom side), 45 nets.

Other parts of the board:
U$1: DP-LOGO
U$2: OSHW_8X350_NOTEXT
U$3: DP_LOGO_ART_1X1

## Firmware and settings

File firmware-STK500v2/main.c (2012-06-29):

/* vim: set sw=8 ts=8 si et: */
/*********************************************
* An implemenation of the STK500 specification (appl. note AVR068) for atmega8
* * Author: Guido Socher, Copyright: GPL
* * Ported to PIC24/Bus Pirate by Ian Lesnet, http://dangerousprototypes.com, 2009
* Copyright: GPL
**********************************************/
#include "base.h"
#include "UART.h"
#include "SPI.h"
#include "command.h"
#include "redefines.h" /* Definitions to get the existing code working with the Bus Pirate */

/* Orig. source defines */
#define CONFIG_PARAM_BUILD_NUMBER_LOW   0
#define CONFIG_PARAM_BUILD_NUMBER_HIGH  1
// be careful with changing HW versions. avrstudio does not like all numbers:
#define CONFIG_PARAM_HW_VER             2 //was 2
// update here our own default sw version:
#define D_CONFIG_PARAM_SW_MAJOR         0x02 //was 2
#define D_CONFIG_PARAM_SW_MINOR         0x0a //was 4

#define CONFIG_PARAM_VTARGET 50
#define CONFIG_PARAM_VADJUST 25
#define CONFIG_PARAM_OSC_PSCALE 2
#define CONFIG_PARAM_OSC_CMATCH 1

uint8_t CONFIG_PARAM_SW_MAJOR;
uint8_t CONFIG_PARAM_SW_MINOR;

#define MSG_IDLE 0
#define MSG_WAIT_SEQNUM 1
#define MSG_WAIT_SIZE1 2
#define MSG_WAIT_SIZE2 3
#define MSG_WAIT_TOKEN 4
#define MSG_WAIT_MSG 5
#define MSG_WAIT_CKSUM 6

//set custom configuration for PIC 24F
_CONFIG2(FNOSC_FRCPLL & OSCIOFNC_ON &POSCMOD_NONE & I2C1SEL_PRI)		// Internal FRC OSC = 8MHz
_CONFIG1(JTAGEN_OFF & GCP_OFF & GWRP_OFF & COE_OFF & FWDTEN_OFF & ICS_PGx1) //turn off junk we don't need

static unsigned char msg_buf[295];
static unsigned char param_reset_polarity=1; // 1=avr (reset active=low), 0=at89 (not supported by this avrusb500)
static unsigned char param_controller_init=0;

// handling off addressed larger than 64k words
static unsigned char larger_than_64k=0;
static unsigned char new_address=0;

static unsigned char extended_address=0;
static unsigned long address=0;
static uint16_t saddress=0;

/* transmit an answer back to the programmer software, message is
 * in msg_buf, seqnum is the seqnum of the last message from the programmer software,
 * len=1..275 according to avr068 */
void transmit_answer(unsigned char seqnum,unsigned int len)
{
        unsigned char cksum;
        unsigned char ch;
        int i;
        if (len>285 || len <1){
                // software error
                len = 2;
                // msg_buf[0]: not changed
                msg_buf[1] = STATUS_CMD_FAILED;
        }
        uart_sendchar(MESSAGE_START); // 0x1B
        cksum = MESSAGE_START^0;
        uart_sendchar(seqnum);
        cksum^=seqnum;
        ch=(len>>8)&0xFF;
        uart_sendchar(ch);
        cksum^=ch;
        ch=len&0xFF;
        uart_sendchar(ch);
        cksum^=ch;
        uart_sendchar(TOKEN); // 0x0E
        cksum^=TOKEN;
        wd_kick();
        for(i=0;i<len;i++){
                uart_sendchar(msg_buf[i]);
                cksum^=msg_buf[i];
        }
        uart_sendchar(cksum);
}

/* Act on incomming packet. Comand in msg_buf, seqnum needed for reply */
void programcmd(unsigned char seqnum)
{
        unsigned char tmp,tmp2,addressing_is_word,ci,cj,cstatus;
        unsigned int answerlen;
        unsigned long poll_address=0;
        unsigned int i,nbytes;
        // distingush addressing CMD_READ_EEPROM_ISP (8bit) and CMD_READ_FLASH_ISP (16bit)
        addressing_is_word=1; // 16 bit is default

        switch(msg_buf[0]){
                case CMD_SIGN_ON:
                // prepare answer:
                msg_buf[0] = CMD_SIGN_ON; // 0x01
                msg_buf[1] = STATUS_CMD_OK; // 0x00
                msg_buf[2] = 8; //len
                //strcpy((char *)&(msg_buf[3]),"AVRISP_2"); // note: this copied also the null termination
                msg_buf[3] = 'S'; 
                msg_buf[4] = 'T'; 
                msg_buf[5] = 'K'; 
                msg_buf[6] = '5'; 
                msg_buf[7] = '0'; 
                msg_buf[8] = '0'; 
                msg_buf[9] = '_'; 
                msg_buf[10] = '2';             
				answerlen=11;
                break;

                case CMD_SET_PARAMETER:
                // not implemented:
                // PARAM_VTARGET
                // PARAM_VADJUST
                // PARAM_OSC_PSCALE
                // PARAM_OSC_CMATCH
                if (msg_buf[1]==PARAM_SCK_DURATION){
                        spi_set_sck_duration(msg_buf[2]);
                }else if(msg_buf[1]==PARAM_RESET_POLARITY){
                        param_reset_polarity=msg_buf[2];
                }else if(msg_buf[1]==PARAM_CONTROLLER_INIT){
                        param_controller_init=msg_buf[2];
                }
                answerlen = 2;
                //msg_buf[0] = CMD_SET_PARAMETER;
                msg_buf[1] = STATUS_CMD_OK;
                break;

                case CMD_GET_PARAMETER:
                tmp=0xff;
                switch(msg_buf[1])
                {
                        case PARAM_BUILD_NUMBER_LOW:
                                tmp = CONFIG_PARAM_BUILD_NUMBER_LOW;
                                break;
                        case PARAM_BUILD_NUMBER_HIGH:
                                tmp = CONFIG_PARAM_BUILD_NUMBER_HIGH;
                                break;
                        case PARAM_HW_VER:
                                tmp = CONFIG_PARAM_HW_VER;
                                break;
                        case PARAM_SW_MAJOR:
                                tmp = CONFIG_PARAM_SW_MAJOR;
                                break;
                        case PARAM_SW_MINOR:
                                tmp = CONFIG_PARAM_SW_MINOR;
                                break;
                        case PARAM_VTARGET:
                                tmp = CONFIG_PARAM_VTARGET;
                                break;
                        case PARAM_VADJUST:
                                tmp = CONFIG_PARAM_VADJUST;
                                break;
                        case PARAM_SCK_DURATION:
                                tmp = spi_get_sck_duration();
                                break;
                        case PARAM_RESET_POLARITY:   // is actually write only, list anyhow
                                tmp = param_reset_polarity;
                                break;
                        case PARAM_CONTROLLER_INIT:
                                tmp = param_controller_init;
                                break;
                        case PARAM_OSC_PSCALE:
                                tmp = CONFIG_PARAM_OSC_PSCALE;
                                break;
                        case PARAM_OSC_CMATCH:
                                tmp = CONFIG_PARAM_OSC_CMATCH;
                                break;
                        case PARAM_TOPCARD_DETECT: // stk500 only
                                tmp = 0x8c; // no card ??
                                break;
                        case PARAM_DATA: // stk500 only
                                tmp = 0; 
                                break;
                        default: 
                                break;
                }
                if (tmp ==0xff){
                        // command not understood
                        answerlen = 2;
                        //msg_buf[0] = CMD_GET_PARAMETER;
                        msg_buf[1] = STATUS_CMD_UNKNOWN;
                }else{
                        answerlen = 3;
                        //msg_buf[0] = CMD_GET_PARAMETER;
                        msg_buf[1] = STATUS_CMD_OK;
                        msg_buf[2] = tmp;
                }
                break;

                case CMD_LOAD_ADDRESS:
                address =  ((unsigned long)msg_buf[1])<<24;
                address |= ((unsigned long)msg_buf[2])<<16;
                address |= ((unsigned long)msg_buf[3])<<8;
                address |= ((unsigned long)msg_buf[4]);
                // atmega2561/atmega2560
                //If bit 31 is set, this indicates that the following read/write operation
                //will be performed on a memory that is larger than 64KBytes. This is an
                //indication to STK500 that a load extended address must be executed. See
                //datasheet for devices with memories larger than 64KBytes.
                //
                if (msg_buf[1] >= 0x80) {
                        larger_than_64k = 1;
                }else{
                        larger_than_64k = 0;
                }
                extended_address = msg_buf[2];
                new_address = 1;
                answerlen = 2;
                //msg_buf[0] = CMD_LOAD_ADDRESS;
                msg_buf[1] = STATUS_CMD_OK;
                break;

                case CMD_FIRMWARE_UPGRADE:
                // firmare upgrade is not supported this way
                answerlen = 2;
                //msg_buf[0] = CMD_FIRMWARE_UPGRADE;
                msg_buf[1] = STATUS_CMD_FAILED;
                break;

                case CMD_ENTER_PROGMODE_ISP: // 0x10
                // The syntax of this command is as follows:
                // 0: Command ID 1 byte, CMD_ENTER_ PROGMODE_ISP
                // 1: timeout 1 byte, Command time-out (in ms)
                // 2: stabDelay 1 byte, Delay (in ms) used for pin stabilization
                // 3: cmdexeDelay 1 byte, Delay (in ms) in connection with the EnterProgMode command execution
                // 4: synchLoops 1 byte, Number of synchronization loops
                // 5: byteDelay 1 byte, Delay (in ms) between each byte in the EnterProgMode command.
                // 6: pollValue 1 byte, Poll value: 0x53 for AVR, 0x69 for AT89xx
                // 7: pollIndex 1 byte, Start address, received byte: 0 = no polling, 3 = AVR, 4 = AT89xx
                // cmd1 1 byte
                // cmd2 1 byte
                // cmd3 1 byte
                // cmd4 1 byte
                LED_ON;
                spi_init();
                delay_ms(msg_buf[2]); // stabDelay

                answerlen=2;
                //msg_buf[0] = CMD_ENTER_PROGMODE_ISP;
                // set default to failed:
                msg_buf[1] = STATUS_CMD_FAILED;
                //connect to the target
                i=0;
                // limit the loops:
                if (msg_buf[4]> 48){
                        msg_buf[4]=48;
                }
                if (msg_buf[5] < 1){
                        // minimum byteDelay
                        msg_buf[5]=1;
                }
                while(i<msg_buf[4]){//synchLoops
                        wd_kick();
                        LED_ON; // blink during init
                        delay_ms(msg_buf[3]); //cmdexeDelay
                        i++;
                        spi_mastertransmit(msg_buf[8]);//cmd1
                        delay_ms(msg_buf[5]); //byteDelay
                        spi_mastertransmit(msg_buf[9]); //cmd2
                        delay_ms(msg_buf[5]); //byteDelay
                        LED_OFF;  // blink during init
                        tmp=spi_mastertransmit(msg_buf[10]);//cmd3
                        delay_ms(msg_buf[5]); //byteDelay
                        tmp2=spi_mastertransmit(msg_buf[11]);//cmd4
                        //
                        //7=pollIndex, 6=pollValue
                        if(msg_buf[7]==3 && tmp==msg_buf[6]) {
                                msg_buf[1] = STATUS_CMD_OK;
                        }
                        //7=pollIndex, 6=pollValue
                        if(msg_buf[7]!=3 && tmp2==msg_buf[6]) {
                                msg_buf[1] = STATUS_CMD_OK;
                        }
                        if(msg_buf[7]==0) { //pollIndex
                                msg_buf[1] = STATUS_CMD_OK;
                        }
                        if(msg_buf[1] == STATUS_CMD_OK ) {
                                LED_ON;
                                i=msg_buf[4];// end loop
                        }else{
                                // new try, see e.g chapeter "Serial download" in
                                // data sheet.
                                // in atmega8 it says: give positive reset pulse 
                                //                     and try again
                                // in at90s2313 it says: give positive sck pulse 
                                //                     and try again
                                // One of those datasheets must be wrong!?
                                // Guido thinks that spi_sck_pulse is correct
                                // and will also work for atmega8 given that
                                // the number of synchLoops is at least 32.
                                //spi_reset_pulse();
                                spi_sck_pulse();
                                delay_ms(20); 
                        }
                }
                break;
                
                case CMD_LEAVE_PROGMODE_ISP:
                spi_disable();
                LED_OFF;
                answerlen = 2;
                //msg_buf[0] = CMD_LEAVE_PROGMODE_ISP;
                msg_buf[1] = STATUS_CMD_OK;
                break;

                case CMD_CHIP_ERASE_ISP:
                spi_mastertransmit(msg_buf[3]);
                spi_mastertransmit(msg_buf[4]);
                spi_mastertransmit(msg_buf[5]);
                spi_mastertransmit(msg_buf[6]);
                if(msg_buf[2]==0) {
                        // pollMethod use delay
                        delay_ms(msg_buf[1]); // eraseDelay
                } else {
                        // pollMethod RDY/BSY cmd
                        ci=150; // timeout
                        while((spi_mastertransmit_32(0xF0000000)&1)&&ci){
                                ci--;
                        }
                }
                answerlen = 2;
                //msg_buf[0] = CMD_CHIP_ERASE_ISP;
                msg_buf[1] = STATUS_CMD_OK;
                break;
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
int main(void)
{
        unsigned char ch;
        unsigned char prev_ch=0;
        //unsigned char chr_nl=0; //unused
        unsigned char msgparsestate;
        unsigned char cksum=0;
        unsigned char seqnum=0;
        int msglen=0;
        int i=0;
        uart_init();
        //wd_init();
        LED_INIT;
        LED_OFF;
        //sei(); //enable AVR interrupts
        msgparsestate=MSG_IDLE;
		// default values:
		CONFIG_PARAM_SW_MINOR=D_CONFIG_PARAM_SW_MINOR;
		CONFIG_PARAM_SW_MAJOR=D_CONFIG_PARAM_SW_MAJOR;

        while(1){
                if (msgparsestate==MSG_IDLE){
                        ch=uart_getchar(1);
                }else{
                        ch=uart_getchar(0); //getting extra bytes, use timeout
                }
                // parse message according to appl. note AVR068 table 3-1:
                if (msgparsestate==MSG_IDLE && ch == MESSAGE_START){
                        msgparsestate=MSG_WAIT_SEQNUM;
                        cksum = ch^0;
                        continue;
                }


                if (msgparsestate==MSG_WAIT_SEQNUM){
                        seqnum=ch;
                        cksum^=ch;
                        msgparsestate=MSG_WAIT_SIZE1;
                        continue;
                }

                if (msgparsestate==MSG_WAIT_SIZE1){
                        cksum^=ch;
                        msglen=ch<<8;
                        msgparsestate=MSG_WAIT_SIZE2;
                        continue;
                }

                if (msgparsestate==MSG_WAIT_SIZE2){
                        cksum^=ch;
                        msglen|=ch;
                        msgparsestate=MSG_WAIT_TOKEN;
                        continue;
                }

                if (msgparsestate==MSG_WAIT_TOKEN){
                        cksum^=ch;
                        if (ch==TOKEN){
                                msgparsestate=MSG_WAIT_MSG;
                                i=0;
                        }else{
                                msgparsestate=MSG_IDLE;
                        }
                        continue;
                }

                if (msgparsestate==MSG_WAIT_MSG && i<msglen && i<280){
                        cksum^=ch;
                        msg_buf[i]=ch;
                        i++;
						wdt_reset(); //wd_kick();
                        if (i==msglen){
                                msgparsestate=MSG_WAIT_CKSUM;
                        }
                        continue;
                }
                
				if (msgparsestate==MSG_WAIT_CKSUM){
                        if (ch==cksum && msglen > 0){
                                // message correct, process it
                                wdt_reset(); //wd_kick();
                                programcmd(seqnum);
                        }else{
                                msg_buf[0] = ANSWER_CKSUM_ERROR;
                                msg_buf[1] = STATUS_CKSUM_ERROR;
                                transmit_answer(seqnum,2);
                        }
                        // no continue here, set state=MSG_IDLE
                }
                msgparsestate=MSG_IDLE;
                msglen=0;
                seqnum=0;
				prev_ch=0;
                i=0;
        }
	return(0);
}

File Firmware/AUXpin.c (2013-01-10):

/*
 * This file is part of the Bus Pirate project (http://code.google.com/p/the-bus-pirate/).
 *
 * Written and maintained by the Bus Pirate project.
 *
 * To the extent possible under law, the project has
 * waived all copyright and related or neighboring rights to Bus Pirate. This
 * work is published from United States.
 *
 * For details see: http://creativecommons.org/publicdomain/zero/1.0/.
 *
 *    This program is distributed in the hope that it will be useful,
 *    but WITHOUT ANY WARRANTY; without even the implied warranty of
 *    MERCHANTABILITY or FITNESS FOR A PARTICULAR PURPOSE.
 */
#include "base.h"
#include "procMenu.h"

						//TRISDbits.TRISD5
#define AUXPIN_DIR      BP_AUX0_DIR

						// 20
#define AUXPIN_RPIN     BP_AUX_RPIN 

						// RPOR10bits.RP20R
#define AUXPIN_RPOUT    BP_AUX_RPOUT

extern struct _modeConfig modeConfig;

static enum _auxmode
        {
         AUX_IO=0,
         AUX_FREQ,
         AUX_PWM,
        } AUXmode=AUX_IO;

unsigned long bpFreq_count(void);
unsigned long bpPeriod_count(unsigned int n);

int PWMfreq;
int PWMduty;

//setup PWM frequency using user values in global variables
void updatePWM(void)
{       unsigned int PWM_period, PWM_dutycycle, PWM_div;

        //cleanup timers 
        T2CON=0;                // clear settings
        T4CON=0;
        OC5CON =0; //#BPV4 - should be OC5CON1/2

        if(PWMfreq==0)
        {       AUXPIN_RPOUT = 0;        //remove output from AUX pin
                AUXmode=AUX_IO;
                return;
        }

        if(PWMfreq<4)
        {       //use 256 //actual max is 62500hz
                PWM_div=62;//actually 62500
                T2CONbits.TCKPS1=1;
                T2CONbits.TCKPS0=1;
        }
        else if(PWMfreq<31)
        {       //use 64
                PWM_div=250;
                T2CONbits.TCKPS1=1;
                T2CONbits.TCKPS0=0;
        }
        else if(PWMfreq<245)
        {       //use 8
                PWM_div=2000;
                T2CONbits.TCKPS1=0;
                T2CONbits.TCKPS0=1;
        }
        else
        {       //use 1
                PWM_div=16000;
                T2CONbits.TCKPS1=0;
                T2CONbits.TCKPS0=0;
        }
        PWM_period=(PWM_div/PWMfreq)-1;
        PR2     = PWM_period;   

        PWM_dutycycle=(PWM_period*PWMduty)/100;
        

        //assign pin with PPS
        AUXPIN_RPOUT = OC5_IO;
        // Should be fine on bpv4

        OC5R = PWM_dutycycle;
        OC5RS = PWM_dutycycle;
        OC5CON = 0x6;                   
        T2CONbits.TON = 1;      

        AUXmode=AUX_PWM;

}

//setup the PWM/frequency generator
void bpPWM(void){
        unsigned int PWM_period, PWM_dutycycle, PWM_freq, PWM_div;
        int done;
        float PWM_pd;

        //cleanup timers 
        T2CON=0;                // clear settings
        T4CON=0;
        OC5CON =0;
        
        if(AUXmode==AUX_PWM){ //PWM is on, stop it
                AUXPIN_RPOUT = 0;        //remove output from AUX pin
                //bpWline(OUMSG_AUX_PWM_OFF);
                BPMSG1028;
                AUXmode=AUX_IO;

                if(cmdbuf[((cmdstart+1)&CMDLENMSK)]==0x00)  return; // return if no arguments to function
        }

        done=0;

        cmdstart=(cmdstart+1)&CMDLENMSK;
        //cmdstart&=CMDLENMSK;

        //get any compound commandline variables
        consumewhitechars();
        PWM_freq=getint();
        consumewhitechars();
        PWM_pd=getint();

        //sanity check values
        if((PWM_freq>0)&&(PWM_freq<4000)) done++;
        if((PWM_pd>0)&&(PWM_pd<100)) done++;


        //calculate frequency:
        if(done!=2)//no command line variables, prompt for PWM frequency
        {       cmderror=0;

                //bpWline(OUMSG_AUX_PWM_NOTE);
                BPMSG1029;
                //bpWstring(OUMSG_AUX_PWM_FREQ);
                BPMSG1030;
                PWM_freq=getnumber(50,1, 4000, 0);
        }

        //choose proper multiplier for whole range
        //bpWstring(OUMSG_AUX_PWM_PRESCALE);
        //BPMSG1031;
        if(PWM_freq<4){//use 256 //actual max is 62500hz
                //bpWline("256");
                PWM_div=62;//actually 62500
                T2CONbits.TCKPS1=1;
                T2CONbits.TCKPS0=1;
        }else if(PWM_freq<31){//use 64
                //bpWline("64");
                PWM_div=250;
                T2CONbits.TCKPS1=1;
                T2CONbits.TCKPS0=0;
        }else if(PWM_freq<245){//use 8
                //bpWline("8");
                PWM_div=2000;
                T2CONbits.TCKPS1=0;
                T2CONbits.TCKPS0=1;
        }else{//use 1
                //bpWline("1");
                PWM_div=16000;
                T2CONbits.TCKPS1=0;
                T2CONbits.TCKPS0=0;
        }
        PWM_period=(PWM_div/PWM_freq)-1;
        //bpWstring("PR2:");
        //BPMSG1032; 
        //bpWintdec(PWM_period);        //echo the calculated value
        //bpBR;
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

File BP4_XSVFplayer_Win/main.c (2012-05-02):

#include <stdio.h>
#include <stdlib.h>
#include <unistd.h>
#include <string.h>
#include <sys/stat.h>
#include <fcntl.h>
#ifdef WIN32
#include <conio.h>
 #include <windef.h>

#else
//#include <curses.h>
#endif

#include "serial.h"
#include "buspirate.h"


#define  JTAG_RESET        0x01
#define  JTAG_CHAIN_SCAN   0x02
#define  XSVF_PLAYER       0x03


#define XSVF_ERROR_NONE            0x00
#define XSVF_ERROR_UNKNOWN         0x01
#define XSVF_ERROR_TDOMISMATCH     0x02
#define XSVF_ERROR_MAXRETRIES      0x03
#define XSVF_ERROR_ILLEGALCMD      0x04
#define XSVF_ERROR_ILLEGALSTATE    0x05
#define XSVF_ERROR_DATAOVERFLOW    0x06
#define XSVF_ERROR_LAST            0x07
#define XSVF_READY_FOR_DATA        0xFF

//#ifndef WIN32
#define usleep(x) Sleep(x);
//#define Sleep(x) usleep(x);
#define TRUE 1
#define FALSE 0
//#endif

char *dumpfile;
#ifdef WIN32
HANDLE dumphandle;
#endif

int modem =FALSE;
int cnt=0;
uint8_t *bin_buf;
uint32_t bin_buf_size;
#define FREE(x) if(x) free(x);
#define MAX_BUFFER 4096
//#define MAX_BUFFER 255  //255 bytes

//http://www.whereisian.com/files/j-xsvf_002.swf

int print_usage(char * appname)
{
		//print usage
		printf("\n");
		printf("\n");
	    printf(" Help Menu\n");
        printf(" Usage:              \n");
		printf("   %s  -p device -f filename.xsvf -s speed [-x] [-r] \n ",appname);
		printf("\n");
		printf("   Example Usage:   %s -p COM1 -s 115200 -f example.xsvf  \n",appname);
		printf("\n");
		printf("           Where: -p device is port e.g.  COM1  \n");
		printf("                  -s Speed is port Speed  default is 115200 \n");
		printf("                  -f Filename of XSVF file \n");
		printf("                  -x Perform a JTAG Chain Scan by sending 0x02 command. -f is optional. \n");
		printf("                  -r Perform a JTAG Reset  Scan by sending 0x01 command. -f is optional. \n");
		printf("\n");

        printf("-----------------------------------------------------------------------------\n");


		return 0;
}

int main(int argc, char** argv)
{
	int opt;
	uint8_t buffer[MAX_BUFFER]={0};
	uint8_t temp[2]={0};  // command buffer
//	struct stat stbuf;
	int fd,timeout_counter;
	int res,c, nparam_bytechunks, bytePointer, readSize;
	long fileSize;
	FILE *XSVF;
//	int  xsvf;
    int timer_out=0;
	char *param_port = NULL;
	char *param_speed = NULL;
	char *param_XSVF=NULL;
	char *param_bytechunks=NULL;
	int  jtag_reset=FALSE;
    int  chainscan=FALSE;

    const char *XSVF_ERROR[]={  "XSVF_ERROR_NONE",
                                "XSVF_ERROR_UNKNOWN",
                                "XSVF_ERROR_TDOMISMATCH",
                                "XSVF_ERROR_MAXRETRIES",
                                "XSVF_ERROR_ILLEGALCMD",
                                "XSVF_ERROR_ILLEGALSTATE",
                                "XSVF_ERROR_DATAOVERFLOW",
                                "XSVF_ERROR_LAST",
                                "XSVF_READY_FOR_DATA",
                                 0 };

	printf("-----------------------------------------------------------------------------\n");
	printf("\n");
	printf(" BusPirate XSVF Player V.02\n");
	printf(" http://www.dangerousprototypes.com\n");
	printf("\n");
	printf("-----------------------------------------------------------------------------\n");



	if (argc <= 1)  {
		print_usage(argv[0]);
		exit(-1);
	}


	while ((opt = getopt(argc, argv, "s:p:f:rx")) != -1) {

		switch (opt) {
			case 'p':  // device   eg. com1 com12 etc
				if ( param_port != NULL){
					printf("Device/PORT error!\n");
					exit(-1);
				}
				param_port = strdup(optarg);
                break;
            case 'r':
                jtag_reset=TRUE;
                break;
            case 'x':
                chainscan=TRUE;
            	break;
			case 'f':
				if (param_XSVF != NULL) {
					printf(" No XSVF file \n");
					exit(-1);
				}
				param_XSVF = strdup(optarg);

				break;

			case 's':
				if (param_speed != NULL) {
					printf(" Speed should be set: eg  115200 \n");
					exit(-1);
				}
				param_speed = strdup(optarg);

				break;

			default:
				printf(" Invalid argument %c", opt);
				print_usage(argv[0]);
				exit(-1);
				break;
		}
	}

	if (param_port==NULL){
		printf(" No serial port specified\n");
		print_usage(argv[0]);
		exit(-1);
	}

    nparam_bytechunks=MAX_BUFFER;

	if (param_speed==NULL) {
		param_speed=strdup("115200");  //default is 115200kbps
	}


	fd = serial_open(param_port);
	if (fd < 0) {
		fprintf(stderr, " Error opening serial port\n");
		return -1;
	}

	//setup port and speed
	serial_setup(fd,(speed_t) atoi(param_speed)); 
	
//--- Added JM
    res = BP_EnableBinary(fd); // Activate Binary mode (Sends 20 OxOO)
    if (res == ERR){
       printf (" Unable to activate BP4 Binary mode \n");
       return -1;
       };
    res = BP_EnableMode(fd,0x18); // Activate XSVF Player Sub-Mode
    if (res == ERR){
       printf (" Unable to activate XSVF player mode \n");
       return -1;
       };
    
//--- End added JM

	if (jtag_reset==TRUE){
        printf(" Performing Reset..\n");
        temp[0]=0x01;
        serial_write( fd, (char *)temp, 1 );
        Sleep(1);
        printf(" Done \n\n");
	}

	// perform Chain scan
	 // Send 0x02 to perform a chain scan
     // Wait for 1 byte, the number of bytes that will be returned
     // Get that many bytes
	if (chainscan==TRUE) {
		printf(" Performing Chain Scan..\n");
		temp[0]=0x02;
		serial_write( fd, (char *)temp, 1 );
		Sleep(1);
		res=0;
		timeout_counter=0;

//		while (res==0) {
        while ((res<=0) && (timeout_counter < 5)) {  // Modified JM
			res= serial_read(fd, (char *)buffer, sizeof(buffer));
			Sleep(1);
			timeout_counter++;
        }  // Line Added JM

/* //--- Removed JM        
		if (timeout_counter>=5) {
			printf(" Got no reply for a Chain scan\n");
			} else {
			printf(" Waiting for a chain scan reply\n");
			}
		}  //--- End removed JM */
	
		if (res >0) {
			printf(" Chain Scan Result:" );
			for(c=0;c<res;c++){
			printf(" %02X",buffer[c]);
			}
//---  Added JM
         }
		else
			printf(" Got no reply for a Chain scan. res = %x, timeout_counter = %x",res,timeout_counter);
//--- End added JM
			printf("\n\n");

		}
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

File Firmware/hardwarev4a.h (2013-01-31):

/*
 * This file is part of the Bus Pirate project (http://code.google.com/p/the-bus-pirate/).
 *
 * Written and maintained by the Bus Pirate project.
 *
 * To the extent possible under law, the project has
 * waived all copyright and related or neighboring rights to Bus Pirate. This
 * work is published from United States.
 *
 * For details see: http://creativecommons.org/publicdomain/zero/1.0/.
 *
 *    This program is distributed in the hope that it will be useful,
 *    but WITHOUT ANY WARRANTY; without even the implied warranty of
 *    MERCHANTABILITY or FITNESS FOR A PARTICULAR PURPOSE.
 */
//This profile is for the Bus Pirate v4 hardware only.
#define BP_VERSION_STRING "Bus Pirate v4"// (Seeed Studio)"
#define BP_VERSION "v4"

// If you want to route AUX1 to channel 7 of the JTR SUMP mode in firmware
// then uncomment this line. Otherwise you can "GREEN WIRE" pins 42 to 55
// on the PIC@$FJ256GB106 or just have 6 channels that do not include AUX1

#define BPv4_SUMP_SOFT_WIRE
#define NUM_OF_SUMP_CHANNELS 8

//this configures the placement of the serial port for 
//the PC side terminal interface
//the other modules should be similarly abstracted, but since v0A and v1a share pins, it doesn't mater
#define BP_TERM_TX		U1TX_IO;
#define BP_TERM_TX_RP  	RPOR1bits.RP2R
#define BP_TERM_RX		RPINR18bits.U1RXR
#define BP_TERM_RX_RP	11


//this is a different type of pin identifier used by the bitbang library
#define AUX2                    0b1 //B0
#define MOSI                    0b10 //B1
#define CLK                     0b100 //B2
#define MISO                    0b1000 //B3
#define CS                      0b10000 //B4
#define AUX0                    0b100000 //B5
#define SUMP_SPARE6             0b1000000 //B6
#define SUMP_SPARE7             0b10000000 //B7
#define AUX1                    0b100000000 //B8

#define IOPOR                   PORTD
#define IOLAT                   LATD
#define IODIR                   TRISD
#define ALLIO                   (MOSI+CLK+MISO+CS)
#define AUX                     AUX0

//these macros set the pin IO used in each module
#define BP_MOSI                 PORTDbits.RD1
#define BP_CLK                  PORTDbits.RD2
#define BP_MISO                 PORTDbits.RD3
#define BP_CS                   PORTDbits.RD4
#define BP_AUX0                 PORTDbits.RD5 //moved pin5 (AUX) to RB10
#define BP_LEDMODE              PORTBbits.RB8 //single MODE led on v2a
#define BP_VREGEN               PORTBbits.RB9 //single vreg enable pin on v2a
#define BP_PULLUP               PORTEbits.RE4 //Pull-up pin on V2a
#define BP_PGD                  PORTBbits.RB7 //PGD pin on programming header
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

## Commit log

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2011-04-18 Stalled projects
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2011-05-08 Updates: swap location of 2 USB connector and power supply section to make the USB connection much shorter and closer main chip. Disconnect USB D- and microSD's DATA2 line, I this this is mis-connect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
2011-07-26 Added variant with flipped shrouded case for the Shrouded 2x5 PTH header
2011-07-26 updated BusPirate-v3.5b, flipped shrouded header case, header notch is now facing inside
    [BusPirate-v3.5b-SSOP.brd, BusPirate-v3.5b-SSOP.sch]
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2011-08-19 Bus Pirate LCD adapters 2, 2a,2b.
    [BP.LCDadapter.v2.brd, BP.LCDadapter.v2.csv, BP.LCDadapter.v2.sch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]
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2011-08-24 Bus Pirate v3.5a SOIC for DIY PCBs
    [BusPiratev3.5a-SOIC.brd, BusPiratev3.5a-SOIC.sch]
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2011-08-29 firmware with open USB stack, not working.
    [baseIO.c, main.c]
2011-08-29 Changes on v1b 3.3V routed additional address control lines, change pull up resistor to network resistor type, shorten the board edge to fit on the ISA bracket, reside configuration text to fit.
2011-08-30 Fixed doublebuffering on BPv4
    [baseIO.c, main.c]
2011-08-30 Fixed interrupts with bootloader on BPv4
    [baseIO.c]
2011-08-31 Device can go faster fix, LED and self-test updates from Tayken.
    [hardwarev4a.h]
2011-09-03 Two new Bus Pirate v4 LCD adapters
    [BPv4-LCDv3.brd, BPv4-LCDv3.sch, BPv4-PassiveLCDv1.brd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]
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2011-09-04 on 3.3V v1b -put a solder jumper for the CPLD voltage select, default is with 3.3V VREG and the jumper is open, there should be no VREG when in 5V and the jumper should be shorted out. -HDD activity 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
    on 5V v1b
    -copy the 3.3V v1b board and removed the VREG (minor changes)
2011-09-04 New solder jumper in eagle library and BPv4 LCD adapters.
    [BPv4-LCDv3.brd, BPv4-LCDv3.sch, BPv4-PassiveLCDv1.brd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]
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2011-09-25 USB stack interrupt fixes
    [baseIO.c, main.c]
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2011-10-06 fixed JP1 and JP2 labels, added ground vias near CPLD ground pin and decoupling cap grounds
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2011-10-13 Bus Pirate v3.5d -silk update and gerbers
    Bus Blaster v2.7
    -pin AC5 of FT2232H was connected to pin1 (GCK) of CPLD
    -swapped some connections to allow shorter traces
    [BusPirate-v3.5d-SSOP.brd]
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2011-10-16 added new board with alternate routing of version 2, connect source of external HDD LED to VCC(5V), fix some text.
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2011-10-25 slight corrections to the pcb,
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2011-10-30 Merged my local copy with svn
    - added smd 7seg,
    - added header1x8,
    - added header2x4,
    - added jumperdescrip 2x2
    - added MAX14500.dev.scr
    - added pic12f508/9
    - added pic10f22x
    - added PIC24FJ256GB106
    - added several rgd leds
    - added USB2514
    - fixed several headers which had the first pin set wrong.
    - changed dfn/qfn footprint to aid handsoldering.
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2011-11-14 - fixed jumper 2x2 description (silkscreen) - DP-LOGO was messed up, fixed
2011-11-15 added the MCLR diode, and the zener footprrint, also added the 3V3 pin ot the analog in jack. and reworked the jumper table
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2011-11-18 fixed the PEM/PWM silk screen error
2011-11-22 added new DP logo
    [BusPirate-v3.5c-SSOP.brd, BusPirate-v3.5d-SSOP.brd, BusPirate-v4b.brd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]
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2011-12-10 added big DP logo on the following boards
    [BP.LCDadapter.v2c.brd, BP.LCDadapter.v2c.sch, BusPirate-v4b.brd]
2011-12-12 Replaced 1-wire with BrentBXR's public domain libraries.
    [1wire.c]
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2011-12-14 Bunched up the components together a bit, so that it would fit the 60 x 37 mm board
    [BusPirate-v3.5e-SSOP.brd, BusPirate-v3.5e-SSOP.sch]
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2011-12-16 Bus pirate 4c board. 4066 changed to tssop, and components bunched up to fit the 60x30 cases
    [BusPirate-v4c.brd, BusPirate-v4c.sch]
2011-12-16 Bus pirate 3.5d updated to fit the 60x37 case, it is aligned to perfectly fit BP4c.
    [BusPirate-v3.5d-SSOP.brd, BusPirate-v3.5e-SSOP.sch]
2011-12-16 Disabled reset from software; instead a message to use the reset button. I also had to remove this from the '?' to allow room for the new e options. (moved around a bit to fit nicely. BXR
2011-12-17 Made two translation packages; one for v3 and below and one for v4. this update is to make it automatic. The correct translation files will be selected by using the correct MCP project and uncommenti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
    Added a version selection in base.h for the current hardware to select the correct h file
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2011-12-17 Changed static messages in uart_getbaud function to BPMSG system. Also added the static 'no software reset on v4' to BPMSG for both v3 and v4 files.
    [UART.c]
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2011-12-19 I tested all these small v4 updates on the v3 and found a couple small issues in the seperate translation files. there now fixed. BXR
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2011-12-21 AVRDude 40x speedup improvement. WARNING: uses polling of UART bits, will not work on v4 yet! Needs AVRDude patch to work: http://dangerousprototypes.com/forum/viewtopic.php?f=41&t=2629
2011-12-21 Updated BBIO mode to not reset on v4 (crashes). Emulates BBIO reset for AVRDude
    [binIO.c, main.c]
2011-12-21 fixed BPv4 spi PPS bug
2011-12-21 Fixed v4 PPS for LCD, SPI, and UART. AUX pin still needed.
2011-12-22 Bus Pirate v3.5e and v4c: centered USB and Connector for both boards LEDs and connectors positions are same on both boards
    [BusPirate-v3.5e-SSOP.brd, BusPirate-v3.5e-SSOP.sch, BusPirate-v4c.brd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]
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2011-12-25 BPv4 Live Monitor UART macro glitch fix. Same stated as for v3, there is ALOT of room for improvment for this macro. but this should still work due to the USBs own buffer stack. BXR
    [UART.c]
2011-12-26 Relised the Auto Baud detection macro disabled UART but did not return UART back to an enabled state. This update should fix it. BXR
    [UART.c]
2011-12-27 I moved all the PPS related stuff into the hardware.h files. I kept the unchanged stuff commented out; once its forsure working we can delete that junk. I also found a couple more lines in SPI that n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
    [hardwarev1a.h, hardwarev3.h, hardwarev4a.h]
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2011-12-28 IR Sample mode PWM frequency fix
2011-12-28 Cleanup a little bit. Added the on-board EEPROM defines (address,min,max,...). Added the only other broken out PINs PPS (why not) ADC. added 'BP_BUTTON_ISDOWN' define (so you can 'if(BP_BUTTON_ISDOWN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
    [hardwarev4a.h]
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2011-12-30 Fixed an issue with the new BRG calculation macro and added the text to BPMSG translation files. BXR
    [UART.c]
2011-12-30 Replaced 'Input BRG Value' to 'Input Custom BAUD rate' and calculates the BRG for you. This is only available on BPv4; same with the MACRO. BPv3 still uses BRG value and no macro; which will be remov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
    [UART.c]
2011-12-30 Deleted the BRG calculation macro now that you can input a custom BAUD instead of BRG value now anyways. Deleted translations as they are no longer used. BXR
    [UART.c]
2011-12-30 changes based on dsm's comments
    [BusPirate-v3.5e-SSOP.brd, BusPirate-v3.5e-SSOP.sch, BusPirate-v4c.brd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]
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2012-01-04 more updates: moved holes' center 4mm from the corner, holes are not plated, moved push buttons of v4c moved ICSP connectors of v3.5e and v5c moved USB connectors of v3.5e and v5c
    [BusPirate-v3.5e-SSOP.brd, BusPirate-v3.5e-SSOP.sch, BusPirate-v4c.brd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]
2012-01-04 Bus Pirate firmware v6 final
    [BusPirate-v3.5c-SSOP.brd, BusPirate-v3.5c-SSOP.sch, BusPirate-v3a-final.brd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]
2012-01-04 Moving Bus Pirate SVN to DP SVN
    [BusPirate-SMPS.brd, BusPirate-SMPS.sch]
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2012-01-06 -changed PCB's corner radius to 4mm
    [BusPirate-v3.5e-SSOP.brd, BusPirate-v3.5e-SSOP.sch, BusPirate-v4c.brd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]
2012-01-07 -made adjustments to the labels on the board
    [BusPirate-v3.5e-SSOP.brd, BusPirate-v4c.brd]
2012-01-09 IR Toy RC5 decoder mode timer update reverted after further investigation: http://dangerousprototypes.com/forum/viewtopic.php?f=29&t=3342&view=unread#p33715
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2012-01-12 Just fixed a small warning about unused variable message upon building by putting it behind a hardware version define (BUSPIRATEV2)? in Main.c BXR
    [main.c]
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2012-01-15 Initial programming adapter for BPv4 schematic added, SMPS code does not block other BP functions
    [bp_pic_programmer_v2.sch]
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2012-01-17 PicProgrammer v2 schematic corrections
    [bp_pic_programmer_v2.sch]
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2012-01-18 PicProgrammer v2 schematic and code update for new pin selections.
    [bp_pic_programmer_v2.sch]
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2012-01-19 added pad terminal for binding post connection, the package is in 4.1mm hole diameter
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2012-01-19 PicProgrammer v2 board layout added
    [bp_pic_programmer_v2.brd]
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2012-01-20 Pic programmer v2 component placement and routing changed for making it smaller
    [bp_pic_programmer_v2.brd, bp_pic_programmer_v2.sch]
2012-01-26 Minor routing change and silkscreen for pin functionalities
    [bp_pic_programmer_v2.brd, bp_pic_programmer_v2.sch]
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2012-01-30 Updated values in schematic and some minor label touchups
    [bp_pic_programmer_v2.brd, bp_pic_programmer_v2.sch]
2012-02-02 redesign PCB symbol, added keepout on the DP6037 pcb
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2012-02-08 BPv3 lcd adapters on standard pcbs...along with gerbers
    [BP.LCDadapter.v3.brd, BP.LCDadapter.v3.sch]
2012-02-08 BP4 LCD adapter V4 on a standard case, along with gerbers
    [BPv4-PassiveLCD.v4.brd, BPv4-PassiveLCD.v4.sch]
2012-02-08 Bus Pirate V3 and V4 programing adapter files, (1 and 2 moved to standard pcbs...along with gerbers
    [bp_pic_programmer_v3.brd, bp_pic_programmer_v3.sch, bp_pic_programmer_v4.brd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]
2012-02-08 fix 4.1mm round pad, turned on the solder mask "stop" on the pad's property
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2012-02-09 fixed DP10062_V1. removed duplicated holes that gives an error in DRC
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2012-02-13 updates: added DP logo on top silk, CC-0 and OSHW logo at the back, fix power select text to USB and EXT for USB and External power, added label for 6-9V external supply, change version to v1a, moved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
2012-02-14 updated bus pirate v3.5e board.
    [BusPirate-v3.5e-SSOP.brd, BusPirate-v3.5e-SSOP.sch]
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2012-02-14 added: - 5050 rgb led - SO-8 package for PIC12(L)F1822
    changed:
    - added pin1 indicator for so-8 package
    - fixed silkscreen for so-8
2012-02-15 updated v3.5 and v4 board to the new DP6037 standard PCB
    [BusPirate-v3.5e-SSOP.brd, BusPirate-v3.5e-SSOP.sch, BusPirate-v4c.brd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]
2012-02-15 updated v4 board. Fixed SWV33 trace that trespass on the mounting hole's keepout. gerber files created
    [BPv4-PassiveLCD.v4.brd]
2012-02-16 updated BP accessories: HV programming adapter for bus pirate V3 and V4 Made the female IO header location fixed with the Bus Pirate IO header 8.5mm from board edge in x axis.
    [bp_pic_programmer_v3.brd, bp_pic_programmer_v3.sch, bp_pic_programmer_v4.brd]
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2012-02-17 Bus Pirate v4c minor revisions External power header location is now @ (3 27) in mm. Fixed the two out of grid vias mentioned to (1 29), (8 36) in mm. Make all vias drill uniform: 20mil - signal and 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
    Bus Pirate v3.5e SSOP minor revision
    Make all vias drill uniform: 20mil - signal and grounds, 30mil for power traces
    Updated gerbers
    [BusPirate-v3.5e-SSOP.brd, BusPirate-v4c.brd]
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2012-03-14 Reverted v1's gerber and images. Added v1a gerber and images too.
2012-03-14 revert v1's gerber and schematic image. Added v1a gerber and brd and schematic images.
2012-03-14 reverted v1 board and schematic image and gerber. Added v1a board and schematic image and gerber
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2012-03-27 updated v1a board to v1b, widen PIC and Reset Pads for easy soldering
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2012-03-29 update DP eagle library, added ATMEGA32U4, MAX6921. updated the SOIC-28W package to have a larger pads, updated small tactile switch footprint to have a larger pads too. fix center of VFD IV 22 displ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
2012-03-29 updated Bus Blaster v4.0 board. Fix connection between FT2232 1.8V output to CPLD 1.8V supply pins
2012-04-05 Fixes that annoying 'unsued var i' error
    [main.c]
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2012-04-12 PiratePICProg: Commited patches from AndThen (PIC32MX), PIC32 still needs work. Added verbose debugging print (so far buspirate and serial module). Fixed PIC24 readout support, fixed endiannes of rea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
2012-04-30 updated Bus Pirate v3.6. In Standard DP6037 PCB, version labels updated to v3.6
    [BusPirate-v3.6-SSOP.brd, BusPirate-v3.6-SSOP.sch]
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2012-05-04 Bus Pirate v4 firmware update. fixed type in USB stack. Fixed include in project file.
    [main.c]
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2012-05-16 Fix UART transparent mode for BPv4 and allow exit from tranparent mode with Normal button
    [UART.c]
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2012-05-24 removed base to collector resistor on T5, add base to emitter 10k resistor on T5, change value of resistors R16, R18, R19 to 10k, change value of resistor R15 to 1k, update trimmer to new footprint, 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
2012-05-25 Added: FT230X, fix footprint of Tact switch and trimmer
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2012-05-30 Fix FT230X SSOP-16 footprint, added SSOP-16-FTDI footprint
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2012-06-04 SPIsniffer app Speed fix for some PCs on serial port initialization: http://dangerousprototypes.com/forum/viewtopic.php?f=4&t=4109&view=unread#p41202
    [main.c]
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2012-06-07 fix 2x05 and 2x07 shrouded pin header. made the silk a little larger to fit on actual header
2012-06-08 update Bus pirate v3.6 to v3.6a. Fix IO shrouded header 2x05 to correct silk length.
    [BusPirate-v3.6a-SSOP.brd, BusPirate-v3.6a-SSOP.sch]
2012-06-12 bus pirate binmode SPI speed fix from: http://dangerousprototypes.com/forum/viewtopic.php?f=40&t=3864#p38949
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2012-06-27 USB descriptor and PID fix ( http://dangerousprototypes.com/track/view.php?id=39 bug fix)
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2012-07-13 baseIO.c : UART1RXRdy() define is converted to function to be consistent with BPv4. This also fixes compilation error in BPv3 due to changes in previous revision.
    Workspaces, translation etc.. : File names renamed with BPv3 and BPv4 prefixes consistency.
    [baseIO.c]
2012-07-13 update board to v1d, fix "Fulfillment" spelling
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2012-07-25 Update for BP v4 Passive LCD adapter v1a -renamed to BPv4LCDadapter v1b -added 74HC595 serial to parallel -removed polarity jumpers? (2x03) of LCD backlight -added control transistor of the backlight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
    [BPv4LCDadapter.v4b.brd, BPv4LCDadapter.v4b.sch]
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2012-08-14 small fix to BPv4 bootloader (comment in wrong place)
    http://dangerousprototypes.com/forum/viewtopic.php?f=28&t=3441&start=45#p42466
    [boot_config.h]
2012-08-14 Added USB interrupt fix to BPv4 from: http://dangerousprototypes.com/forum/viewtopic.php?f=28&t=3441&start=45#p42038
    [main.c]
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2012-08-27 update to blog theme with header fix, switch for contest theme.
2012-08-27 update ATX PSU v1.2: expanded ATX Connector drill pads from 1.4mm to 1.7mm, "Fulfillment" spelling fixed
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2012-09-07 Fix IN-12 socket, replaced with correct cutout.
2012-09-07 Added: IN-12 Nixie tube display, IN-12 Socket cutout footprint Fixed: IN-12 Socket
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2012-09-13 .lib and .mod files converted using eagle2kicad-0.d.ulp from http://www.modulbot.com/download.html Fixed undefined DRAW command when loading to symbol library to KiCAD
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2012-09-26 swapped drain and source pin of the p-mosfet controlling fuse blown switch
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2012-10-18 correcting the naming for the 2512 resistor model
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2012-10-18 Added device: MicrosSD fold type socket, PIC24F16KA102, 1x2 SMD solder jumper. fix Arduino 1x8 header containing pin 8 - 13, offset ed location.
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2012-10-28 Retrieved demo board v5 files from previous revision, and renamed the wrongly named v5a into proper names
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2012-11-19 BP v4d, buspirate v4 fitted into a bigger DP PCB (DP7043)
    [BusPirate-v4d.brd, BusPirate-v4d.sch]
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2012-11-22 fix, ICSP pogo pin programmer footprint by adding a pad on the keyhole for a key pogo pin to be soldered
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2012-12-07 added BP v4e, fix odd angled placement, no 45 degrees placement anymore. replaced ICSP header with miniature ICSP footprint
    [BusPirate-v4e.brd, BusPirate-v4e.sch]
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2012-12-14 fix pad, changed via to a pad. new board named v1b
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2012-12-20 revert back DP Standard PCB with the label name indicating its PCB size
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2013-01-09 Patches applied for Bus Pirate Tracker isues 66 and 73 http://dangerousprototypes.com/track/view.php?id=66 http://dangerousprototypes.com/track/view.php?id=73
    66: bpWlongdecf() fails to correctly print out some values
    73: Improving Frequency Measurement Resolution & Gremlins
    patch 66 baseIO.c bpWlongdecf() function tested, and working.
    Patch 73 untested, but compiles and doesn't break any of the functions.
    [AUXpin.c, baseIO.c]
2013-01-10 Bus Pirate - AUXpin.c. Cleaned the code a bit, deleted a huge commented out section, and applyed the patch in issue #65 http://dangerousprototypes.com/track/view.php?id=65
    [AUXpin.c]
2013-01-11 Bus Pirate firmware -v4 pull up voltage control add to bin protocol. as per issue 63 http://dangerousprototypes.com/track/view.php?id=63 patch available at the link above, and is applied to rev2082
    [1wire.c, UART.c, binIO.c]
2013-01-11 Bus Pirate firmware - the issue 50 solution. r (reads) are now posible to switch the display modes on the fly with simple d,b,x comands.. rd,rx,rb brind DEC, BIN, and HEX respectfully
2013-01-14 A slight change in variable definition in procMenu.c, and indent fix in I2C.c
2013-01-16 Bus Pirate firmware issue 51 minor fix to the protos function pointer array, in the BP_USE_I2C section. nulfunc changed to I2Cstop.. http://dangerousprototypes.com/track/view.php?id=51
2013-01-17 Bus Pirate firmware version change to v6.3 + Issues 57 and 24 ...
    Version change to 6.3 - We're clearing out the backlog of issues so it's a perfect time for a version change to 6.3
    issue 57
    http://dangerousprototypes.com/track/view.php?id=57
    a clutch is added between the setup process and the start of using a protocol, Once setup is done all the pins are still at HiZ. only when you type in the 'W' commend does the clutch engage - pins are actualy connected to peripherals...
    issue 24
    http://dangerousprototypes.com/track/view.php?id=24
    Since the PPS peripherals ignore the TRIS bits, seting or clearing of TRIS bits was never implemented, so the 'v' commmand readss outputs as inputs. I added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
    [UART.c, pc_at_keyboard.c]
2013-01-25 Added PTH 2x7 0.1" header, fix TSSOP-20 footprint pad arrangement, fix 74AC573 TSSOP-20 pin numbering
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2013-01-28 Bus Pirate Firmware - issue 53. Basic scripting engine put back into v6.2.... http://dangerousprototypes.com/track/view.php?id=53
2013-01-31 Bus Pirate Firmware issue #89 - adding UART communications in debugging mode, to activate, #define BPV4_DEBUG, to deactivate comment it out in base.h.. This lets you to connect your debugger and run 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
    [baseIO.c, hardwarev4a.h, main.c]
2013-02-11 fix ICSP 0.1 inch header pin 5 made it to a circular pad. added proto pads with 1.2mm diameter drills
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2013-02-19 Mark pin 1 of DIP8, DIP14, DIP14W as this is automatically changed to a square pad by DRC check. Corrected SO-8's name and values labels to their proper layers
2013-02-21 add BP v3.8 I/O arrangement changed to 5V - GND VPU - 3V3 AUX - ADC MISO - CS MOSI - CLK
    [BusPirate-v3.8-SSOP.brd, BusPirate-v3.8-SSOP.sch]
2013-03-07 updates on v3.8 USB connector now in micro-B All SMD LEDs are in LED603 IO shrouded header fix, notch is facing outward not much change on the USB D+ D- line just did route them to have almost the sa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
    [BusPirate-v3.8-SSOP.brd, BusPirate-v3.8-SSOP.sch]
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2013-03-07 revert connection of MISO, MOSI, CS and CLK like bp v3.6 MOSI-RP6 CLK-RP7 MISO-RP8 CS-RP9
    [BusPirate-v3.8-SSOP.brd, BusPirate-v3.8-SSOP.sch]
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2013-07-24 bus pirate: fix slashes and filename case for linux compatibility
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2014-02-23 SPI mode } command was giving errors, busPirateCore.c line 225 now maps to SPIstop for stopR. Should fix it. Untested.
2014-03-21 correct EEPROM for v2/2.5, v3c and v4a, old EEPROM value was non 3.3V compliant (93C46), replaced with 93LC46B. updated schematic, wiki, BOM/Partlist. Board and gerbers still the same
2014-03-23 changed VR1, VR2 LDO regulators to MCP1801T-3302I/OT and VR3 to MCP1801T-5002I/OT. to fix the issue on LDO output voltage oscillation due to the usage of ceramic caps on the output of each LDO. these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
    [BusPirate-v3.5-SOIC.brd, BusPirate-v3.5-SOIC.sch, BusPirate-v3.5-SSOP.brd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]
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2014-08-28 added bus pirate v3.8a a compact bus pirate v3.8 fitted within 5x5cm SoB board
    [BusPirate-v3.8a-SSOP.brd, BusPirate-v3.8a-SSOP.sch]
2014-08-29 -replaced SMD version for the IO and ICSP header -fixed over hang distance of header including USB connector to 1.25mm -gerber generated
    [BusPirate-v3.8a-SSOP.brd, BusPirate-v3.8a-SSOP.sch]
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2014-09-03 board update: -changed ICSP header to 6pins, spare pin not connected -moved all LEDs a little to the right for even space
    [BusPirate-v3.8a-SSOP.brd, BusPirate-v3.8a-SSOP.sch]
2018-01-04 added v3.9 hardware, a SoB square bus pirate for educational purpose. Modification are: I/O pins to 10-pin JST connector and USB-min-B to USB-micro-B
    [BusPirate-v3.9-SSOP.GBL, BusPirate-v3.9-SSOP.GBO, BusPirate-v3.9-SSOP.GBP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]
2018-02-21 - Change IO connector to 0.1 PTH right angled shrouded - Change USB connector - Change LEDs from 0603 to 0804 - Fix texts orientation
    [BusPirate-v3.9-SSOP.GBL, BusPirate-v3.9-SSOP.GBO, BusPirate-v3.9-SSOP.GBP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]
2018-03-21 Bus pirate in a DP5050 SoB board -in micro usb connector -right angled shrouded 0.1" PTH IO connector -0805 LEDs -pull down resistor on VREG enable -revised pull up circuitry
    [BusPirate-v5.0-SSOP.GBL, BusPirate-v5.0-SSOP.GBO, BusPirate-v5.0-SSOP.GBP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]
2018-09-10 Added v5 hardware with different USB Micro B style connectors
    [BusPirate-v5.0-SSOP.GBL, BusPirate-v5.0-SSOP.GBO, BusPirate-v5.0-SSOP.GBP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]
